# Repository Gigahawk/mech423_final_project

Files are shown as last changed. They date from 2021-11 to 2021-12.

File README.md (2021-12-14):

# LitePog

LitePog is a clone of the [Light Pong](https://www.playlightpong.com/) game.

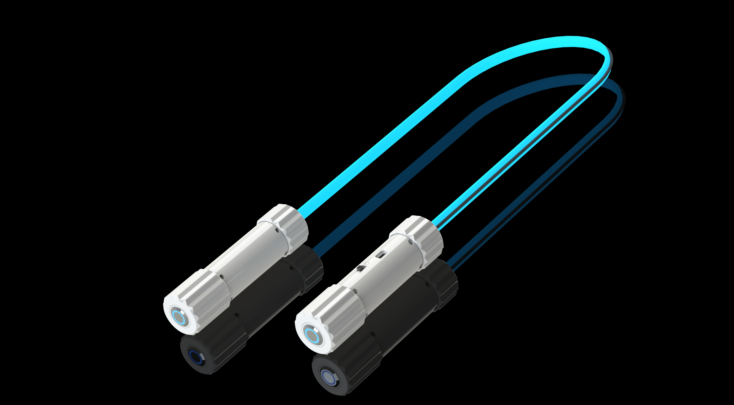
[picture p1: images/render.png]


## Folder Structure
- `firmware`: Code Composer Studio workspace containing firmware for the MSP430FR5739
- `mech`: SolidWorks mechanical CAD files
- `pcb`: KiCad electrical CAD files
- `wiring`: WireViz wire harness diagrams and diagrams.net system wiring diagram
- `proposal`: Initial project proposal for MECH 423 written in LaTeX
- `report`: Final project report for MECH 423 written in LaTeX
- `images`: Images for this readme

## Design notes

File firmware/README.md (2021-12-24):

# LitePog Firmware

## Config Constants

Hardware specific configuration should go inside `config.h`.

## Building

Ensure you are building for the correct target platform:
Right click project > `Build Configurations` > `Set Active` > your platform.

## Design Spec

### Terminology

- `Button 1`: The button connected to the logic PCB
- `Button 2`: The button connected to the power PCB
- `Handle 1`: The handle containing the logic PCB
- `Handle 2`: The handle containing the power PCB
- `Ball`: Single pixel of light that players must keep from reaching their handle
- `Return Zone`: Area that the ball must be in for a player to interact with the ball (in certain game modes)

### Revision 2

The following notes are for the specification designed below, implemented as of [firmware_rev2](https://github.com/Gigahawk/mech423_final_project/tree/firmware_rev2/firmware) (commit hash 8e8a770)

#### Playtest Notes

- Game Select Mode
    - Works well, reasonably intuitive given the lack of buttons
- Play Mode
    - Return zone should not be pure blue, probably best to make the hue slightly different to improve contrast
    - **Pong**
        - Works much better than Rev 1
        - Better anti-spam may be required
            - Cooldown between button presses to penalize double presses
    - **Ping Pong**
        - Works as expected
        - Anti-spam works fine
    - **Tug o' War**
        - May be better to experiment with how exactly the button interacts with the ball
            - Buttons should probably change the velocity of the ball instead of position directly
                - In this case there should be some natural decay of the ball speed towards 0 so that it doesn't move if nothing is pressed.
            - Should investigate benefits of punishing/helping losing player (when ball is near their handle)

#### Specification
The following will outline the expected behavior of LitePog.

##### Game Select Mode

1. User powers up LitePog while holding down Button 2
2. LitePog displays the demo animation of the currently selected game, as well as a rainbow pattern near Handle 2
3. User(s) can choose the next or previous games by pressing Button 1 or Button 2
4. The selection is saved to FRAM when the device is turned off

##### Play Mode

1. User powers up LitePog with no buttons held down.
2. LitePog displays the demo animation of the currently selected game
    - LitePog leaves idle animation when both buttons are held
3. Game count down starts
    - One or two red pixels in the middle light up, and grows outwards at regular interval
    - Once the countdown ends, all red pixels turn green
    - If either player releases their button at this point, return to the demo animation
4. Game is active
    - See below for game types
5. Display game end animation
    - Winner side blinks green, loser side blinks red
    - Return to idle animation after a few seconds

##### Pong

1. The first player to release their button spawns the ball in the middle, the ball starts travelling away from this player
2. Once the ball reaches the return zone of a player, (indicated by their button lighting up), they must press their button to return the ball
    - The return zone should be a few pixels in width
    - If the player fails to return the ball, the game ends

##### Ping Pong

1. The first player to release their button spawns the ball in the middle, the ball starts travelling away from this player
2. Once the ball reaches the return zone of a player, (indicated by their button lighting up), they must press their button to return the ball
    - The return zone should take up half of the light strip
    - If the player fails to return the ball, the game ends
    - If a player presses their button while the ball is not in their return zone and travelling towards them, the game ends

##### Tug o' War

1. The first player to release their button spawns the ball in the middle, the ball starts travelling away from this player
2. Each time the players press a button, the ball moves one pixel away from them
3. If the ball reaches a player's handle, the game ends

### Revision 1

The following notes are for the specification designed below, implemented as of [firmware_rev1](https://github.com/Gigahawk/mech423_final_project/tree/firmware_rev1/firmware) (commit hash 97b537f)

#### Playtest Notes

- Timing is both too slow and too fast
    - Movement of ball between handles takes too long, but the window to return a ball is too small, no good middle ground exists
        - Solution(s):
            - Player should be able to return the ball when the ball reaches a few LEDs prior to the last one (button should light up a few LEDs earlier)
                - This gives greater flexibility to find timing values that are both fun and challenging to play with.
            - Implement the game as shown in the promo video (see below)
- No speaker
    - No solution, the commercial product has more room due to injection molded parts, and more freedom with PCB sizing.
- Only one game mode
    - The commercial product appears to have extra buttons for game selection
        - Solution: Game select mode is handled by holding down the power handle button while flicking the switch, then the two buttons can be used to scroll through the game types.
        The selected game type is stored in FRAM, then the user power cycles the unit, and a demo animation unique to the game starts playing
    - Game Types from [promo video](https://www.youtube.com/watch?v=iOcHVvs48tQ):
        - Ping Pong:
            - Similar to current game, but player can press button to return the ball any time as soon as it passes the middle point.
            - Player loses if they push the button while it's on the other player's side
                - There is also supposedly anti-spam code, although this seems redundant
                - It may be fun to have a mechanic to incentivize waiting for longer before returning the ball (risks losing the game if player waits too long and the ball reaches their end) some potential examples:
                    - Ball returns faster depending on how close it is to the player
                    - Opponents reigion to return the ball gets smaller
        - Rev & Release:
            - This appears to be a single player game where you hold the button to shoot the ball down the tube, then release at a certain point.
                - Single player games don't look very fun, and will not be implemented
        - Tug o' War:
            - Each player button mashes to move the ball closer to the opponent side (think [egg blowing game](https://www.youtube.com/watch?v=yyNyL65NAKE) but less gross)
                - The commercial game uses buttons that are much nicer to spam with, this may cause pain on our buttons
        - Cyclone:
            - I have no idea how this is supposed to work, but this also appears to be a single player game.
                - Single player games don't look very fun, and will not be implemented

#### Specification
The following will outline the expected behavior of LitePog.

1. User powers up LitePog
2. LitePog displays its idle animation
    - LED strip displays either a rainbow cycling effect (power source permitting), or a simple dot moving back and forth.
    - Buttons light up when pressed
    - LitePog leaves idle animation when both buttons are held
3. Game count down starts
    - One or two red pixels in the middle light up, and grows outwards at regular interval
    - Once the countdown ends, all red pixels turn green
    - If either player releases their button at this point, return to the idle animation
4. Game is active
    - The first player to release their button spawns the ball in the middle, the ball starts travelling away from this player
5. Ball reaches player
    - The player must press the button when the ball reaches their side (indicated by the button lighting up) to continue the rally
    - If the player fails to return the ball, the game ends
6. Display game end animation
    - Winner side blinks green, loser side blinks red
    - Return to idle animation after a few seconds

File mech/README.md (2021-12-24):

# LitePog Mechanical CAD

Mechanical CAD files for LitePog

## Exporting for 3D Printing

To export parts for 3D printing, open them in SolidWorks and save as `.3MF`.

Some parts contain multiple bodies, when importing the `.3MF` files into a slicer, ensure each body is treated as a separate part.

All parts should be printable without supports.
> Note: bridges and overhangs may not print well, but they will not be visible from the outside nor cause interference issues.

The list of required parts is:
- `strip_holder.SLDPRT` x2
- `strip_collar.SLDPRT` x2
- `button_plate.SLDPRT` x2
- `button_spacer.SLDPRT` x2
- `button_collar.SLDPRT` x2
- `handle_core.SLDPRT`
    - `logic_handle` configuration x1
    - `power_handle` configuration x1

## Rev 2 Notes

The following notes refer to [mech_rev2](https://github.com/Gigahawk/mech423_final_project/tree/mech_rev2) (commit hash a1e2143).

Hardware has not been validated as of 2021-12-16, however it is likely that this revision will be functional out of the box.

Notable changes:
- PCBs are now centered within handle
    - Power switch sticks out less
    - USB-C countersink is deeper
- External screws have been removed
    - Screw holes were left unused during rev 1 testing
- Optimizations for 3D printing
    - Fewer overhangs
    - Wall thickness is more consistent
- Alignment features for shim pieces
    - Removal of screws means there the old alignment procedure no longer works, so this is now integrated into the design

## Rev 1 Notes

The following notes refer to [mech_rev1](https://github.com/Gigahawk/mech423_final_project/tree/mech_rev1/mech) (commit hash a887341).

### Playtest Notes
- Button placement is uncomfortable
    - Solutions:
        - Make handle's more narrow
            - Handle size is largely constrained by PCB design, which needs to be cost-effective (within 10x10cm), and easy to assemble.
        - Place button on side
            - Will require major redesign
        - Use a bigger/protruding arcade style button
            - Ideal for a next revision, but arcade buttons can be expensive

### Assembly Notes
- Thread features work smoothly
- LED strip clamp could be better designed
    - Currently the clamping force is transmitted through hot glue covering the LED strip solder joints
- Wall thickness is insufficient in many areas
    - Some areas are unfixable, like screw holes
- Screw holes are unnecessary
    - Sandwich mount works fine with just the collars holding the pieces together

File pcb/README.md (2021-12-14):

# LitePog PCB

PCB files for LitePog

## Rev 2 Bring-Up Notes

The following notes refer to [pcb_rev2](https://github.com/Gigahawk/mech423_final_project/tree/pcb_rev2/pcb) (commit hash 8e8a57b).

Hardware has not been validated as of 2021-12-13, however it is likely that this revision will be functional out of the box.

## Rev 1 Bring-Up Notes

The following notes refer to [pcb_rev1](https://github.com/Gigahawk/mech423_final_project/tree/pcb_rev1/pcb) (commit hash f791dd6).

All hardware (with modifications) has been validated as of 2021-11-27.

### Logic Handle (assembled 2021-11-17)
Logic handle was assembled and tested over multiple days:
- 2021-11-17: Initial bring up and testing of all components
- 2021-11-24:
    - Validate Neopixel function with 3.3V logic level
    - Fix transistor connection for button LED

Notes:
- MCU appears to work fine
    - Can be programmed as expected
    - Resonator `Y1` not populated for now, likely not necessary
        - Firmware can rely entirely on DCO
- Power supply works fine
    - Produces 3.3V as expected
- Level shifter doesn't work
    - Level shifter U2 is designed to be connected between open-drain (or push-pull) pins, not to be connected directly to buttons or LEDs.
    - Solutions:
        - Remove/bypass the shifter (**Current solution as of 2021-11-17**)
            - The only strictly 5V level interface is the Neopixel strip, although it is fairly likely to work at 3.3V
            - All other IO is OK to run at 3.3V
            - *EDIT 2021-11-24: Neopixel strip works fine with 3.3V logic signals, level shifter has been removed, and all bypass jumpers set*
        - Use shifters with explicit transfer directions
            - Will need multiple chips, but this will allow all IO to be 5V
        - Only shift the Neopixel data line
            - Minimizes chips, ideal solution for next revision
- LED transistor `Q1` is wired incorrectly
    - Current always flows through body diode regardless of input
    - Solutions:
        - Short `LED-` and `LED1` (*Solution from 2021-11-17*):
            - This inverses the LED on polarity (Set `LED1` to let current flow, high to stop)
            - This sinks 20 mA into the GPIO pin, not ideal.
            - This may cause problems/uneven lighting across the interconnect due to voltage drop.
                - The transistor on the power PCB appears to be correct
        - Flip transistor on PCB (**Current solution as of 2021-11-24**)
            - Pins 1 and 2 need to be swapped (pins on same side of IC), which means pin 3 will be facing the other way. It just so happens that there is a ground pad at approximately the right distance away from the actual transistor footprint that would make this work (or some of the silkscreen can be scratched away)
            - *CORRECTION 2021-11-24: pins 2 and 3 need to be swapped, this was done by rotating IC 180 degrees.*
            *Pin 1 was left floating, which was connected back to R8 with a bodge wire.*
        - Fix transistor configuration in schematic(swap drain and source)
            - ideal solution for next revision
- *EDIT 2021-12-06: LED strip connector `JNPX1` should be moved towards the center by 0.5 to 1mm to avoid interference with the casing.*

### Power Handle
Power handle was assembled over multiple days:
- 2021-11-26: bring up and testing of critical components (boost, charging, protection, in that order)
- 2021-11-27: assemble misc components (connectors, battery holder, button circuitry)
- 2021-12-09: Final testing of safety features

Notes:
- Boost circuit works as designed, capable of producing high current (> 1A continuous for 10 seconds)
- Boost circuit can not be turned off
    - The datasheet for PAM2423 indicates that setting the `EN` pin low only disables the IC's boosting function, it does not turn off the output since there is a direct path from input to output via the inductor and diode.
    - Solutions:
        - Use switch to cut off input current (**Current solution as of 2021-11-26**)
            - Done by cutting the traces going to the input, and running wires to `SW1`.
                - `SW1` is already connected to `BATT+` to drive the `EN` pin, add an extra wire to allow high current flow
            - The EG1224 is only rated for 0.5A, finding higher current switches in this form factor is hard
                - EG2219 is a DPDT switch rated for 0.5A per pole, which can theoretically be combined for 1A total current, but this is still impractical because the input must provide more than 1A current at peak loads
                - Testing at 1A output current (~ 2A input current) seems to be fine (tested for ~10 seconds)
            - This is the simplest solution for this revision, since it does not require `EN` to be rewired, nor does it allow the boost converter to continually drain the battery from quiescent current.
            - There is a risk of arcing if switch is disconnected during high load, although this has not been observed, and should never happen in normal operation
        - Use switch to cut off output current
            - Similar issues to cutting off input current, although current requirements on the output are lower
            - Boost converter will be constantly on, and drawing quiescent current from battery
            - There is a risk of arcing if switch is disconnected during high load, although this has not been observed, and should never happen in normal operation
        - Use MOSFET to switch input current
            - Switch input from high side using a PMOS
            - Ideal solution for next revision
- Charging circuit appears to work as expected
    - LED comes on when plugged in and battery is below max voltage
    - LED turns off when max voltage is reached
    - *EDIT 2021-12-09: Full discharge and charge cycle tested. Charging cutoff occurred at 4.2V as expected*
- Protection circuit appears to work as expected
    - Datasheet for BQ2970 indicates that it must be bootstrapped the first time by connecting a charger to the battery, which was observed
    - *Note: protection features are largely untested*
        - Over discharge current protection is set high enough that it cannot trip
            - This is intentional, we want to allow the battery to provide as much current as necessary for the boost converter
            - A battery capable of providing the necessary current without overheating is being used
        - Short circuit protection is untested
            - This would involve shorting `BATT+` to ground, which is unlikely to happen in regular operation
            - This safety feature is typically intended for standalone battery protection boards that provide user accessible output terminals that could be accidentally shorted
        - Under voltage protection is untested
            - It is time-consuming to wait for the battery to completely drain while monitoring the voltage to ensure that the cutoff protection works.
            - Periodic checking of the battery voltage during firmware development should take place to ensure the battery voltage is within safe levels
            - *EDIT 2021-12-09: Full discharge and charge cycle tested.*
                - Output was shut off at a safe voltage (VBAT ~2.9V when measured, but it may have risen slightly due to hysteresis)
                - It is unclear which chip is actually responsible for cutting off the battery, both the PAM2423 boost converter and the BQ29703DSET protection chip is rated for an under voltage lockout of 2.5V, although it is likely both chips are working as expected.
        - Over voltage protection is untested
            - The charging circuit stops charging the battery prior to the over voltage protection threshold
        - Over charge current protection is untested
            - The charge current of the charging circuit is fixed at 500mA, and should never be high enough to trigger over charge current protection
- Bypass diode `D2` is left unpopulated
    - Theoretically it should be safe to populate, however it is unknown if this will cause adverse behavior with the boost circuit.
    - Populating this diode will prevent the output from being turned off with the switch when `VBUS` is present
- Aluminum capacitors `C10` and `C1` are not structurally sound
    - Should be reinforced with hot glue

### Button Harness (Assembled 2021-11-24)
- Works as expected

### Neopixel Strip (Assembled 2021-11-24)
- Removing provided connectors is rather hard
    - Nearly damaged the pads while removing old joints
    - Simpler solution for next revision is to order more LEDs than required and cut off first one to access unsoldered pads

### Interconnect Harness (Assembled 2021-11-24)
- Works as expected
- Very time-consuming to assemble, set aside more time to do this next revision

### Mock Power Handle (Assembled 2021-11-27)
- Assembled board with bypass diode `D2` connecting the USB connector directly to `VCC`, and button circuitry for use in firmware testing.

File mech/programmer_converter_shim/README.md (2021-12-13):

# MSP-EXP430FR5739 Programmer Breakout Shim

CAD files to support the  [programmer_converter](https://github.com/Gigahawk/mech423_final_project/tree/master/pcb) PCB when connected to the MSP-EXP430FR5739 board.

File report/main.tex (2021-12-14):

\documentclass{notes}
\begin{document}
\vspace*{\fill}
\begin{center}
    {\centering\huge{LitePog}}\\
    \vspace*{2em}
    {\centering\huge{MECH 423 Project Report}}\\
    \vspace*{2em}
    {\large Jasper Chan: 37467164 }\\
    {\large Jacky Chang: 19835164 }
\end{center}
\vspace*{\fill}
\newpage

\begin{abstract}
    The objective of this project is to design and create a simple two player game similar to Light Pong\footnotemark.
    \footnotetext{
        \url{https://www.kickstarter.com/projects/aaqib/light-pong-game}
    }
    The system will consist of two handles/controllers on each end of a flexible tube that houses an LED strip.
    The MSP430 will be used to control the LED's and process the signals from each controller.
    The mechanical housing was designed in SolidWorks and printed in PLA using Fused Deposition Modelling (FDM).
    The PCBs were designed in KiCad and ordered from JLCPCB.

    The game was slightly different from the original Light Pong.
    Our version starts in an idle state and requires both players to hold down their buttons to start a countdown.
    At the end of the countdown the first player to let go launches the "ball" and the light begins to move towards the opposing player.
    Players wait until the button on their handle lights up at which point they would need to press the button before a specified elapses.
    If they fail to do so the game ends, and they lose, if they do press the button in time, the light moves towards the other player at a slightly increased speed.
    This process repeats until one player misses.
\end{abstract}

\section{Objectives}

The project is largely a re-implementation of the Light Pong Kickstarter.
All critical functions of the device were completed, including functional PCBs, a 3D printed housing, and the firmware implementing the game logic.

The only planned feature that was not completed on time was sourcing a translucent/transparent silicone tube to protect the LED strip and wiring.

\section{Rationale}

It's interesting to reverse engineer a product and see what type of difficulties the original developers may have experienced along the way.
The product is still currently only available for preorder, and units are not slated to ship until Q3 2022.
Because it can't be purchased, this is a good opportunity to have a similar device without waiting for preorders to start shipping.

\section{Summary of Functional Requirements}

\begin{table}[H]
    \centering
    \begin{tabularx}{\textwidth}{>{\hsize=.6\hsize\raggedright}X>{\hsize=.1\hsize\raggedright}X>{\hsize=.3\hsize\raggedright\arraybackslash}X}
        Task                                                                    & Effort & Person Responsible \\\toprule
        Power + charging PCB capable of delivering enough current for LED strip & 20\%   & Jasper             \\\midrule
        Microcontroller PCB to drive LED strip and read button inputs           & 20\%   & Jasper             \\\midrule
        Mechanical housing for parts                                            & 20\%   & Jacky              \\\midrule
        Addressable LED Strip                                                   & 5\%    & Jacky              \\ \midrule
        Microcontroller code                                                    & 35\%   & Jasper and Jacky   \\\bottomrule
    \end{tabularx}
    \caption{Functional Requirements and their efforts}
    \label{tab:funcreq}
\end{table}

\section{Functional Requirement 1: Addressable LED strip}

\subsection{Approach and Design}

The most common addressable LED strips on the market are all based on the WS2812B (commonly referred to as Neopixels).
The general rule of thumb is that each LED may consume up to \SI{60}{\milli\ampere} of current, although this rarely happens when displaying patterns on the strip since not all LEDs will be on/at full power.
For our application, Adafruit sells\footnotemark\ a \SI{1}{\meter} long strip with 30 LEDs.
\footnotetext{\url{https://www.adafruit.com/product/1376}}
This provides an acceptable balance between LED density and current consumption.

These LEDs are typically rated for \SI{5}{\volt} power and logic, however they can commonly be driven at lower voltages.
In order to determine the power requirements for the power PCB, experimentation will have to be done.

\subsection{Inputs and Outputs}

\subsubsection{Inputs}

\begin{enumerate}
    \item Power
          \begin{enumerate}
              \item Voltage: nominally \SI{5}{\volt}, actual TBD
              \item Current: Max \SI{60}{\milli\ampere} per LED
          \end{enumerate}
    \item Data: the WS2812B data format is described in the datasheet\footnotemark
          \footnotetext{\url{https://cdn-shop.adafruit.com/datasheets/WS2812.pdf}}
    \item Wiring: Wires between the handles will need to be run along the LED strip
\end{enumerate}

\subsubsection{Outputs}

\begin{enumerate}
    \item Light: the LED strip will emit light
    \item Power: the power wiring inside the LED strip may be used to power the microcontroller PCB
    \item Wiring: Wires between the handles will need to be run along the LED strip
\end{enumerate}

\subsection{Parameters}

\begin{enumerate}
    \item Strip length
          \begin{enumerate}
              \item Adafruit sells strips in \SI{1}{\meter} segments, but they can be cut in between each LED
              \item A \SI{1}{\meter} strip will be used for convenience
          \end{enumerate}
    \item LED count
          \begin{enumerate}
              \item Adafruit sells strips at various LED densities
              \item Higher densities will increase power and memory requirements on the MCU
          \end{enumerate}
\end{enumerate}

\subsection{Development Plan}

For simplicity, a \SI{1}{\meter} strip with 30 LEDs will be used.

A \SI{3.3}{\volt} logic level microcontroller will be used to determine if the strip can be controlled without the use of a level shifter.

A bench power supply will be used to determine if a \SI{5}{\volt} boost circuit will be needed to power the LEDs.

\subsection{Test Plan}
\label{sec:fr1testplan}

\subsubsection{Logic level requirements}
\begin{enumerate}
    \item Power the LED strip with \SI{5}{\volt} from a bench power supply
    \item Connect a \SI{3.3}{\volt} logic level MCU to the data pin of the strip
    \item Attempt to display a test pattern, if this works, a level shifter is not required, if this does not work, redo the test with a level shifter.
\end{enumerate}

\subsubsection{Brightness requirements}
\begin{enumerate}
    \item Power the LED strip with \SI{5}{\volt} from a bench power supply
    \item Connect an MCU to the data pin of the strip
    \item Set all LEDs to full brightness white (RGB 255, 255, 255)
    \item Incrementally turn down the brightness until it is at a reasonable level
\end{enumerate}

\subsubsection{Voltage requirements}
\begin{enumerate}
    \item Power the LED strip with \SI{3.2}{\volt} from a bench power supply
    \item Connect an MCU to the data pin of the strip
    \item Set all LEDs to a reasonable brightness of white
    \item If the LEDs turn on correctly, note the current consumption, if not, repeat the test at a higher voltage until the LED strip reliably turns on.
          \begin{itemize}
              \item This will determine if we need a boost circuit or if the LEDs can be directly powered from a LiPo battery.
          \end{itemize}
\end{enumerate}
\subsubsection{Results}

The LED strip was capable of being controlled with \SI{3.3}{\volt} level logic signals from the MSP430.

It was determined that running the LEDs at about 100/255 brightness was a reasonable number that was clearly visible while keeping the current consumption manageable.

Powering the LED strip at less than \SI{5}{\volt} was not tested since it was determined that a boost converter was necessary to utilize the entirety of the battery capacity.

\subsection{Integration}
\begin{enumerate}
    \item Power the LED strip with the determined acceptable voltage level
    \item Connect MCU (with level shifter if required) to the data pin of the strip
    \item Display a test pattern on the strip
\end{enumerate}

\section{Functional Requirement 2: Power + Charging PCB}
\label{sec:fr2}

\subsection{Approach and Design}

Because there is limited space to store a power source within the handles of the device, a custom PCB will have to be made to hold the battery, and associated charging, protection and boost circuitry as required.

Because the handle will be cylindrical, an 18650 battery will be used because it will be the most convenient form factor while providing high power and energy density.
For safety reasons, a spring-loaded battery holder will be used to avoid soldering or spot welding connections.

\subsection{Inputs and Outputs}

\subsubsection{Inputs}

\begin{enumerate}
    \item Charging power: Battery will be charged with a USB connection
    \item Button: Power PCB will be housed in one of the device handles, and will need to have a connector for the handle button
    \item Button LED signal: Power PCB will need a connection to receive the signal to turn the button's LED on or off
    \item Power Switch: The power PCB will need a power switch to disable the power output
\end{enumerate}

\subsubsection{Outputs}

\begin{enumerate}
    \item LED strip power: Power PCB will need to provide power to the LED strip
    \item Button signal: Power PCB will need to have a connection to deliver the button signal to the MCU
    \item Button LED power: Power PCB will need to light up the button's LED when indicated by the MCU
\end{enumerate}

\subsection{Parameters}

\begin{enumerate}
    \item LED strip voltage: Determined in \autoref{sec:fr1testplan}
    \item Total sustained current: Determined in \autoref{sec:fr1testplan}
    \item Battery choice: Must be capable of providing enough power
          \begin{itemize}
              \item Battery may or may not come with protection circuitry built in.
                    Requirement for protection circuitry on the PCB is only required for unprotected cells.
                    PCB silkscreen will clearly indicate whether protected or unprotected cells should be used.
          \end{itemize}
    \item Charging current: for safety reasons this will be a conservative number (max 1C)
    \item PCB dimensions: PCB must be big enough to hold all the components
\end{enumerate}

\subsection{Development Plan}

\begin{enumerate}
    \item Design schematic and layout of PCB
    \item Send design to PCB house for manufacturing, buy components
    \item Assemble PCB
\end{enumerate}

\subsection{Test Plan}

\subsubsection{Charging}

\begin{enumerate}
    \item Place PCB and USB battery bank inside a fireproof container
    \item Connect USB battery bank to PCB charging input
    \item Wait for charging to complete.
    \item Remove LiPo cell from PCB, ensure that it has the correct voltage for a charged cell (approximately \SI{4.2}{\volt})
\end{enumerate}

\subsubsection{Power Output}

\begin{enumerate}
    \item Place PCB inside a fireproof container
    \item Connect PCB power output to a load
          \begin{itemize}
              \item If the lab contains a programmable load, this is preferred, otherwise the load can just be the LED strip + MCU
          \end{itemize}
    \item Enable PCB power output and load
    \item Ensure power output is stable
    \item Keep test running, ensure power output stops at or before designed battery cutoff voltage is reached.
\end{enumerate}

\subsubsection{Button LED}

\begin{enumerate}
    \item Connect button to PCB
    \item Connect MCU GPIO to PCB
    \item Enable PCB power output
    \item Toggle Button LED GPIO, ensure LED toggles.
\end{enumerate}

\subsubsection{Button Input}

\begin{enumerate}
    \item Connect button to PCB
    \item Connect MCU GPIO to PCB
    \item Enable PCB power output
    \item Press and release button, ensure MCU can read button input.
\end{enumerate}

\subsubsection{Results}

After some modifications\footnotemark, the power PCB functions as expected.
\footnotetext{Modifications are outlined in project files.}

The power PCB was capable of providing \SI{5}{\volt} at \SI{1}{\ampere} continuously for over \SI{10}{\second}, which is more than we ever expect in normal use.
Battery over and under voltage protections worked as expected.
One modification involves running the battery current through the power switch, which exceeds its \SI{500}{\milli\ampere} rating, however no heat or adverse effects were noticed even during prolonged use.

\section{Functional Requirement 3: Microcontroller PCB}

\subsection{Approach and Design}

As required by the class, an MSP430 will be used.
For simplicity, the same MSP430FR5739IDAR\footnotemark as used in Lab 3 will be used, and the design will be derived from the Lab 3 design.
\footnotetext{
    \url{https://www.digikey.ca/en/products/detail/texas-instruments/MSP430FR5739IDAR/2696032}
}

\subsection{Inputs and Outputs}

\subsubsection{Inputs}

\begin{enumerate}
    \item Power: Power will be provided from the PCB board, either via the LED strip, or via a separate wire. Power may have to be stepped down to safely power the MCU
    \item Button x2: MCU PCB will be housed in one of the device handles, and will need to have a connector for the handle button, as well as for the button on the other handle
\end{enumerate}

\subsubsection{Outputs}

\begin{enumerate}
    \item LED strip data: MCU PCB will need to control the LED strip
    \item Button LED power x2: MCU PCB will need to light up the button's LED when indicated by the MCU
\end{enumerate}

\subsection{Parameters}

\begin{enumerate}
    \item Crystal choice: Determine frequency and precision of MCLK source
\end{enumerate}

\subsection{Development Plan}

\begin{enumerate}
    \item Design schematic and layout of PCB
    \item Send design to PCB house for manufacturing, buy components
    \item Assemble PCB
\end{enumerate}

\subsection{Test Plan}

\begin{enumerate}
    \item Power up PCB with bench power supply (use low current limit to minimize risk of shorts)
    \item Check that MCU can be programmed
    \item Program MCU with test firmware
    \item Confirm functionality of all required IO pins with a test program
\end{enumerate}

\subsubsection{Results}

After some modifications\footnotemark, the microcontroller PCB functions as expected.
\footnotetext{Modifications are outlined in project files.}

\section{Functional Requirement 4: Mechanical Housing}

\subsection{Approach and Design}

A custom mechanical housing will have to be designed to house the other components.
To avoid spending too much time or money machining, 3D printing will be primarily used to fabricate mechanical parts.
To make debugging of other components easier, the housing will be designed to be disassembled easily.

\subsection{Inputs and Outputs}

\subsubsection{Inputs}

\begin{enumerate}
    \item Other components: all other components will either be fixed to or contained within the mechanical housing
\end{enumerate}

\subsubsection{Outputs}

\begin{enumerate}
    \item Mechanical stability: parts must be held securely
\end{enumerate}

\subsection{Parameters}

\begin{enumerate}
    \item Handle diameter: diameter must be small enough to be comfortable, but large enough contain the PCBs
    \item Handle length: length must be short enough to be comfortable, but long enough to contain the PCBs
\end{enumerate}

\subsection{Development Plan}

\begin{enumerate}
    \item Once PCBs have been designed, PCB mechanical models will be passed on to the mechanical housing designer
    \item Mechanical housing will be designed around the PCB models
\end{enumerate}

\subsection{Test Plan}

\begin{enumerate}
    \item PCBs (or printed models of the PCBs) will be assembled into the mechanical housings to test fit
\end{enumerate}

\subsubsection{Results}

PCBs were assembled successfully into the housings.

\section{Functional Requirement 5: Microcontroller Code}

\subsection{Approach and Design}

The code for the MCU will need to be written to implement the game behavior.
Once the schematic for the MCU PCB is finalized, code can be written to run on it.

\subsection{Inputs and Outputs}

\subsubsection{Inputs}

\begin{enumerate}
    \item Buttons: The code must read the button inputs at the appropriate time
\end{enumerate}

\subsubsection{Outputs}

\begin{enumerate}
    \item Button LEDs: The code must drive the button LEDs at the appropriate time
    \item LED strip: The code must drive the Neopixel LED strip at the appropriate time with the correct pattern
\end{enumerate}

\subsection{Parameters}

\begin{enumerate}
    \item Game speed: The movement speed of the "ball" will control how hard the game is to play
\end{enumerate}

\subsection{Development Plan}

\begin{enumerate}
    \item Once the schematic is finalized, code can be written for the PCB
\end{enumerate}

\subsection{Test Plan}

\begin{enumerate}
    \item Flash the code on the MCU PCB (or another MSP430 board if the MCU PCB has not been completed)
    \item Hook up the buttons and LED strip and test that the code behaves as expected
\end{enumerate}

\subsubsection{Results}

The code worked as expected, although play testing indicates that changes could be made to improve user experience.

\section{System Evaluation}

See the Results subsections within each Functional Requirements section.

\section{Reflections}

The project for the most part went very smoothly.
We played to our strong points which allowed us to progress quickly; however, it may have proved to be a better learning experience if we worked on our weaker areas.
Some things that we would have done differently is speccing and ordering things earlier.
As a result of this oversight, we were unable to obtain a tube to house the LED strip.
Although the performance didn't suffer, it was still something that we would have liked to have.

The most important things we learned in MECH 423 that we deemed to be the most important are:
\begin{itemize}
    \item Learning how to properly read and interpret documentation
    \item Writing and debugging code
    \item PCB design
\end{itemize}
We picked these three aspects of the course because they are generic topics that are more applicable to the working world as opposed to how to use the MSP430 specifically.
Furthermore, these are things that we believe will be very common for us to use and refer back to as mechatronic engineers; especially within the field of research and development.

Currently, we lack experience implementing mechanical systems.
We have not had very much experience either designing or building a physical system within courses or co-op.
Moving forward, it would be nice to get more practice going through the entire design cycle for a mechanical system so that we may be more proficient in things like designing test jigs or final products.
To acquire this experience, we plan to pursue personal projects with enough difficulty that would challenge our current knowledge and allow us to grow.
We can also achieve this by working in a field that requires rapid iteration and design like a start-up or a research and development position.
\end{document}

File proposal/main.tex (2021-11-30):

\documentclass{notes}
\begin{document}
\vspace*{\fill}
\begin{center}
{\centering\huge{MECH 423 Proposal}}\\
\vspace*{2em}
{\large Jasper Chan: 37467164 }\\
{\large Jacky Chang: 19835164 }
\end{center}
\vspace*{\fill}
\newpage
\section{Objectives}

The objective of this project is to design and create a simple two player game similar to LightPong\footnotemark.
\footnotetext{
    \url{https://www.kickstarter.com/projects/aaqib/light-pong-game}
}
The system will consist of two handles/controllers on each end of a flexible tube that houses an LED strip.
The MSP430 will be used to control the LED's and process the signals from each controller.

\section{Rationale}

It's interesting to reverse engineer a product and see what type of difficulties the original developers may have experienced along the way.
The product is still currently in it's crowdfunding phase, so it's not in full development, and it would be nice to be able to have one to play with.

\section{List of Functional Requirements}

\begin{table}[H]
    \centering
    \begin{tabularx}{\textwidth}
        {
            >{\hsize=.6\hsize\raggedright}X
            >{\hsize=.1\hsize\raggedright}X
            >{\hsize=.3\hsize\raggedright\arraybackslash}X
        }
        Task                                                                    & Effort            & Person Responsible \\\toprule
        Power + charging PCB capable of delivering enough current for LED strip & \SI{20}{\percent} & Jasper             \\\midrule
        Microcontroller PCB to drive LED strip and read button inputs           & \SI{20}{\percent} & Jasper             \\\midrule
        Mechanical housing for parts                                            & \SI{20}{\percent} & Jacky              \\\midrule
        Addressable LED Strip                                                   & \SI{05}{\percent} & Jacky              \\ \midrule
        Microcontroller code                                                    & \SI{35}{\percent} & Jasper and Jacky   \\\bottomrule
    \end{tabularx}
    \caption{Functional Requirements and their efforts}
    \label{tab:funcreq}
\end{table}

\section{Functional Requirement 1: Addressable LED strip}

\subsection{Approach and Design}

The most common addressable LED strips on the market are all based on the WS2812B (commonly referred to as Neopixels).
The general rule of thumb is that each LED may consume up to \SI{60}{\milli\ampere} of current, although this rarely happens when displaying patterns on the strip since not all LEDs will be on/at full power.
For our application, Adafruit sells\footnotemark\ a \SI{1}{\meter} long strip with 30 LEDs.
\footnotetext{\url{https://www.adafruit.com/product/1376}}
This provides an acceptable balance between LED density and current consumption.

These LEDs are typically rated for \SI{5}{\volt} power and logic, however they can commonly be driven at lower voltages.
In order to determine the power requirements for the power PCB, experimentation will have to be done.

\subsection{Inputs and Outputs}

\subsubsection{Inputs}

\begin{enumerate}
    \item Power
    \begin{enumerate}
        \item Voltage: nominally \SI{5}{\volt}, actual TBD
        \item Current: Max \SI{60}{\milli\ampere} per LED
    \end{enumerate}
    \item Data: the WS2812B data format is described in the datasheet\footnotemark
    \footnotetext{\url{https://cdn-shop.adafruit.com/datasheets/WS2812.pdf}}
    \item Wiring: Wires between the handles will need to be run along the LED strip
\end{enumerate}

\subsubsection{Outputs}

\begin{enumerate}
    \item Light: the LED strip will emit light
    \item Power: the power wiring inside the LED strip may be used to power the microcontroller PCB
    \item Wiring: Wires between the handles will need to be run along the LED strip
\end{enumerate}

\subsection{Parameters}

\begin{enumerate}
    \item Strip length
    \begin{enumerate}
        \item Adafruit sells strips in \SI{1}{\meter} segments, but they can be cut in between each LED
        \item A \SI{1}{\meter} strip will be used for convenience
    \end{enumerate}
    \item LED count
    \begin{enumerate}
        \item Adafruit sells strips at various LED densities
        \item Higher densities will increase power and memory requirements on the MCU
    \end{enumerate}
\end{enumerate}

\subsection{Development Plan}

For simplicity, a \SI{1}{\meter} strip with 30 LEDs will be used.

A \SI{3.3}{\volt} logic level microcontroller will be used to determine if the strip can be controlled without the use of a level shifter.

A bench power supply will be used to determine if a \SI{5}{\volt} boost circuit will be needed to power the LEDs.

\subsection{Test Plan}
\label{sec:fr1testplan}

\subsubsection{Logic level requirements}
\begin{enumerate}
    \item Power the LED strip with \SI{5}{\volt} from a bench power supply
    \item Connect a \SI{3.3}{\volt} logic level MCU to the data pin of the strip
    \item Attempt to display a test pattern, if this works, a level shifter is not required, if this does not work, redo the test with a level shifter.
\end{enumerate}

\subsubsection{Brightness requirements}
\begin{enumerate}
    \item Power the LED strip with \SI{5}{\volt} from a bench power supply
    \item Connect an MCU to the data pin of the strip
    \item Set all LEDs to full brightness white (RGB 255, 255, 255)
    \item Incrementally turn down the brightness until it is at a reasonable level
\end{enumerate}

\subsubsection{Voltage requirements}
\begin{enumerate}
    \item Power the LED strip with \SI{3.2}{\volt} from a bench power supply
    \item Connect an MCU to the data pin of the strip
    \item Set all LEDs to a reasonable brightness of white
    \item If the LEDs turn on correctly, note the current consumption, if not, repeat the test at a higher voltage until the LED strip reliably turns on.
    \begin{itemize}
        \item This will determine if we need a boost circuit or if the LEDs can be directly powered from a LiPo battery.
    \end{itemize}
\end{enumerate}

\subsection{Integration}
\begin{enumerate}
    \item Power the LED strip with the determined acceptable voltage level
    \item Connect MCU (with level shifter if required) to the data pin of the strip
    \item Display a test pattern on the strip
\end{enumerate}

\section{Functional Requirement 2: Power + Charging PCB}
\label{sec:fr2}

\subsection{Approach and Design}

Because there is limited space to store a power source within the handles of the device, a custom PCB will have to be made to hold the battery, and associated charging, protection and boost circuitry as required.

Because the handle will be cylindrical, an 18650 battery will be used because it will be the most convenient form factor while providing high power and energy density.
For safety reasons, a spring-loaded battery holder will be used to avoid soldering or spot welding connections.

\subsection{Inputs and Outputs}

\subsubsection{Inputs}

\begin{enumerate}
    \item Charging power: Battery will be charged with a USB connection
    \item Button: Power PCB will be housed in one of the device handles, and will need to have a connector for the handle button
    \item Button LED signal: Power PCB will need a connection to receive the signal to turn the button's LED on or off.
    \item Power Switch: The power PCB will need a power switch to disable the power output.
\end{enumerate}

\subsubsection{Outputs}

\begin{enumerate}
    \item LED strip power: Power PCB will need to provide power to the LED strip
    \item Button signal: Power PCB will need to have a connection to deliver the button signal to the MCU
    \item Button LED power: Power PCB will need to light up the button's LED when indicated by the MCU
\end{enumerate}

\subsection{Parameters}

\begin{enumerate}
    \item LED strip voltage: Determined in \autoref{sec:fr1testplan}
    \item Total sustained current: Determined in \autoref{sec:fr1testplan}
    \item Battery choice: Must be capable of providing enough power
    \begin{itemize}
        \item Battery may or may not come with protection circuitry built in.
        Requirement for protection circuitry on the PCB is only required for unprotected cells.
        PCB silkscreen will clearly indicate whether protected or unprotected cells should be used.
    \end{itemize}
    \item Charging current: for safety reasons this will be a conservative number (max 1C)
    \item PCB dimensions: PCB must be big enough to hold all the components
\end{enumerate}

\subsection{Development Plan}

\begin{enumerate}
    \item Design schematic and layout of PCB
    \item Send design to PCB house for manufacturing, buy components
    \item Assemble PCB
\end{enumerate}

\subsection{Test Plan}

\subsubsection{Charging}

\begin{enumerate}
    \item Place PCB and USB battery bank inside a fireproof container
    \item Connect USB battery bank to PCB charging input
    \item Wait for charging to complete.
    \item Remove LiPo cell from PCB, ensure that it has the correct voltage for a charged cell (approximately \SI{4.2}{\volt})
\end{enumerate}

\subsubsection{Power Output}

\begin{enumerate}
    \item Place PCB inside a fireproof container
    \item Connect PCB power output to a load
        \begin{itemize}
            \item If the lab contains a programmable load, this is preferred, otherwise the load can just be the LED strip + MCU
        \end{itemize}
    \item Enable PCB power output and load
    \item Ensure power output is stable
    \item Keep test running, ensure power output stops at or before designed battery cutoff voltage is reached.
\end{enumerate}

\subsubsection{Button LED}

\begin{enumerate}
    \item Connect button to PCB
    \item Connect MCU GPIO to PCB
    \item Enable PCB power output
    \item Toggle Button LED GPIO, ensure LED toggles.
\end{enumerate}

\subsubsection{Button Input}

\begin{enumerate}
    \item Connect button to PCB
    \item Connect MCU GPIO to PCB
    \item Enable PCB power output
    \item Press and release button, ensure MCU can read button input.
\end{enumerate}

\section{Functional Requirement 3: Microcontroller PCB}

\subsection{Approach and Design}

As required by the class, an MSP430 will be used.
For simplicity, the same MSP430FR5739IDAR\footnotemark as used in Lab 3 will be used, and the design will be derived from the Lab 3 design.
\footnotetext{
    \url{https://www.digikey.ca/en/products/detail/texas-instruments/MSP430FR5739IDAR/2696032}
}

\subsection{Inputs and Outputs}

\subsubsection{Inputs}

\begin{enumerate}
    \item Power: Power will be provided from the PCB board, either via the LED strip, or via a separate wire. Power may have to be stepped down to safely power the MCU
    \item Button x2: MCU PCB will be housed in one of the device handles, and will need to have a connector for the handle button, as well as for the button on the other handle
\end{enumerate}

\subsubsection{Outputs}

\begin{enumerate}
    \item LED strip data: MCU PCB will need to control the LED strip
    \item Button LED power x2: MCU PCB will need to light up the button's LED when indicated by the MCU
\end{enumerate}

\subsection{Parameters}

\begin{enumerate}
    \item Crystal choice: Determine frequency and precision of MCLK source
\end{enumerate}

\subsection{Development Plan}

\begin{enumerate}
    \item Design schematic and layout of PCB
    \item Send design to PCB house for manufacturing, buy components
    \item Assemble PCB
\end{enumerate}

\subsection{Test Plan}

\begin{enumerate}
    \item Power up PCB with bench power supply (use low current limit to minimize risk of shorts)
    \item Check that MCU can be programmed
    \item Program MCU with test firmware
    \item Confirm functionality of all required IO pins with a test program
\end{enumerate}

\section{Functional Requirement 4: Mechanical Housing}

\subsection{Approach and Design}

A custom mechanical housing will have to be designed to house the other components.
To avoid spending too much time or money machining, 3D printing will be primarily used to fabricate mechanical parts.
To make debugging of other components easier, the housing will be designed to be disassembled easily.

\subsection{Inputs and Outputs}

\subsubsection{Inputs}

\begin{enumerate}
    \item Other components: all other components will either be fixed to or contained within the mechanical housing
\end{enumerate}

\subsubsection{Outputs}

\begin{enumerate}
    \item Mechanical stability: parts must be held securely
\end{enumerate}

\subsection{Parameters}

\begin{enumerate}
    \item Handle diameter: diameter must be small enough to be comfortable, but large enough contain the PCBs
    \item Handle length: length must be short enough to be comfortable, but long enough to contain the PCBs
\end{enumerate}

\subsection{Development Plan}

\begin{enumerate}
    \item Once PCBs have been designed, PCB mechanical models will be passed on to the mechanical housing designer
    \item Mechanical housing will be designed around the PCB models
\end{enumerate}

\subsection{Test Plan}

\begin{enumerate}
    \item PCBs (or printed models of the PCBs) will be assembled into the mechanical housings to test fit
\end{enumerate}

\section{Functional Requirement 5: Microcontroller Code}

\subsection{Approach and Design}

The code for the MCU will need to be written to implement the game behavior.
Once the schematic for the MCU PCB is finalized, code can be written to run on it.

\subsection{Inputs and Outputs}

\subsubsection{Inputs}

\begin{enumerate}
    \item Buttons: The code must read the button inputs at the appropriate time
\end{enumerate}

\subsubsection{Outputs}

\begin{enumerate}
    \item Button LEDs: The code must drive the button LEDs at the appropriate time
    \item LED strip: The code must drive the Neopixel LED strip at the appropriate time with the correct pattern
\end{enumerate}

\subsection{Parameters}

\begin{enumerate}
    \item Game speed: The movement speed of the "ball" will control how hard the game is to play
\end{enumerate}

\subsection{Development Plan}

\begin{enumerate}
    \item Once the schematic is finalized, code can be written for the PCB
\end{enumerate}

\subsection{Test Plan}

\begin{enumerate}
    \item Flash the code on the MCU PCB (or another MSP430 board if the MCU PCB has not been completed)
    \item Hook up the buttons and LED strip and test that the code behaves as expected
\end{enumerate}

\section{Most Critical Module}

The most critical module is the power PCB described in \autoref{sec:fr2}.
The power PCB needs to provide stable power to all the other components.
The power PCB will also be the larger of the two PCBs, and will be the limiting factor in how small the handles can be.

\section{Risks and Countermeasures}

\subsection{Parts Shortage}

We are in the middle of a parts and shipping shortage at time of writing.

To mitigate potential shipping delays, designs will be completed as soon as possible so that parts can be ordered as soon as possible.
To mitigate parts potentially being available, a BOM will be kept up to date as the design progresses, and will be periodically checked with DigiKey to ensure that they are still available.
Where possible, PCBs will be designed to support alternative parts.
The most critical part will be the MSP430FR5739IDAR, which at time of writing is still available.
If it is no longer available at time of purchasing, the chip can be salvaged from the PCB from Lab 3.

\subsection{Limited Power}

The battery or circuitry in the power PCB may not deliver enough power to the rest of the system when assembled.

To mitigate limited power output, the USB charging connector and an auxiliary barrel connector will also be routed to the main power output so that the system can be externally powered.

\section{Learning Objectives}

We hope to further develop both electrical and mechanical CAD skills, as well as programming skills.

\end{document}

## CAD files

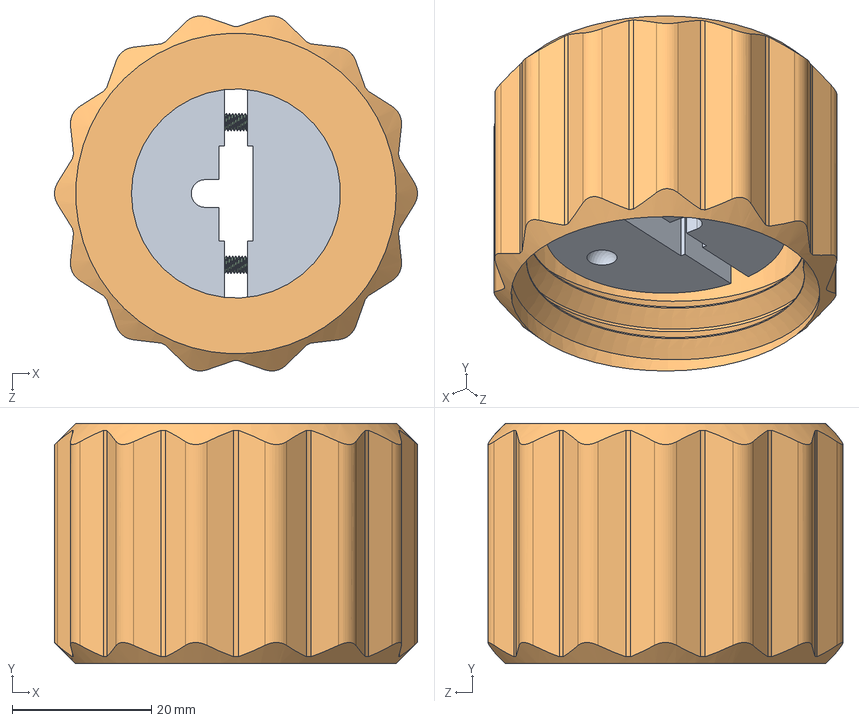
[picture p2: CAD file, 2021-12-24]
mech/strip_holder.SLDASM
52.1 x 34.5 x 50.9 mm
strip_holder
strip_collar
90592A080_Steel Hex Nut x 2
91290A106_Black-Oxide Alloy Steel Socket Head Screw x 2

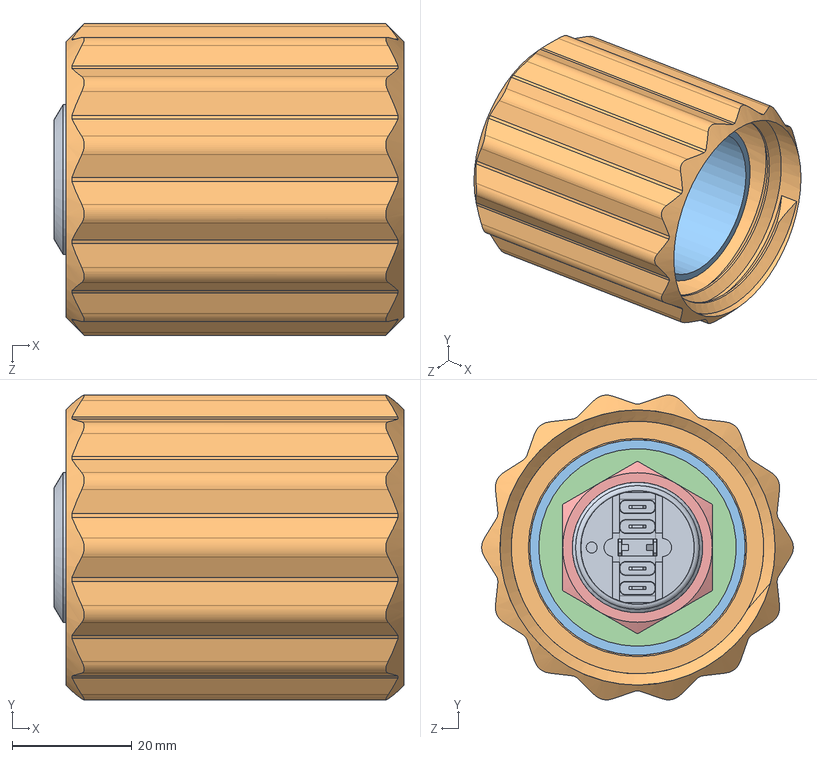
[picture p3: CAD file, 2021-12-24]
mech/button.SLDASM
58.5 x 50.9 x 52.1 mm
PV7F2Y0xx-3xx
button_collar
button_spacer
button_plate
button_nut

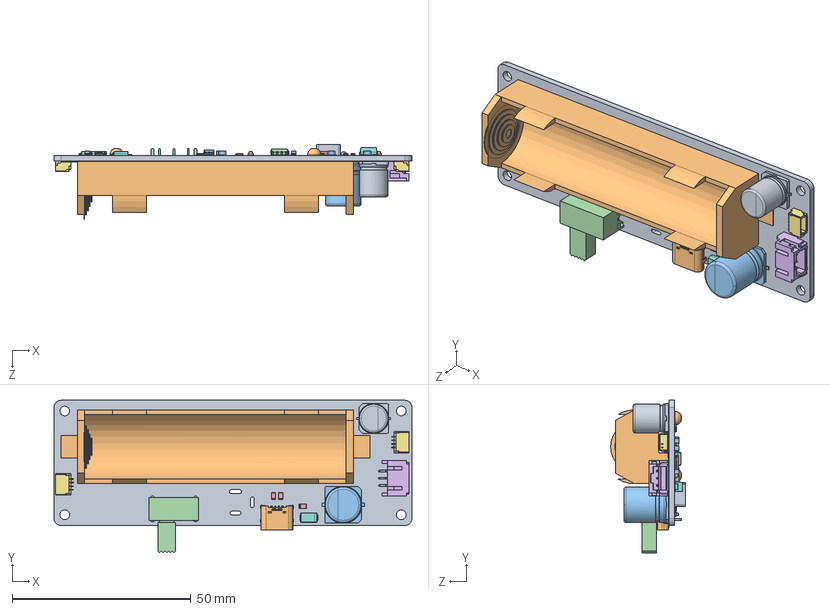
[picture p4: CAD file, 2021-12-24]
mech/power_handle_pcb.SLDASM
100.0 x 42.6 x 20.9 mm
Pcb_ddda.step
UJC-HP-3-SMT-TR.step
C10_CP_Elec_10x126_6184AD54.step
SW1_SW_E-Switch_EG1224_SPDT_Angled_6183ECC2.step
R5_R_0805_2012Metric_6183C6F1.step x 16
JNPX1_S3B-PH-SM4-TB(LF)(SN)_6183D19D.step
JHI1_SM04B-SRSS-TB(LF)(SN)_6183DD0E.step x 2
D4_D_SMA_61848250.step x 2
C1_CP_Elec_8x10_6184FB3E.step
BT1_Keystone_1042_1x18650_6184FC40.step
U1_SOT_23_5_6184FD53.step
Q4_SOIC_8_39x49mm_P127mm_61B79016.step
U2_HSOP_8_1EP_39x49mm_P127mm_EP241x31mm_6183C879.step
U3_WSON6_15x15mm_Pitch05mm_6183C88F.step
Q3_SOT_323_SC_70_6183C69C.step
Q2_LFPAK56_61845DD0.step x 2
L1_ASPI-0630LR-6R8M-T15_6183C61F.step
D6_LED_0603_1608Metric_6183C53E.step x 3
C9_C_0805_2012Metric_6183C4BD.step x 8

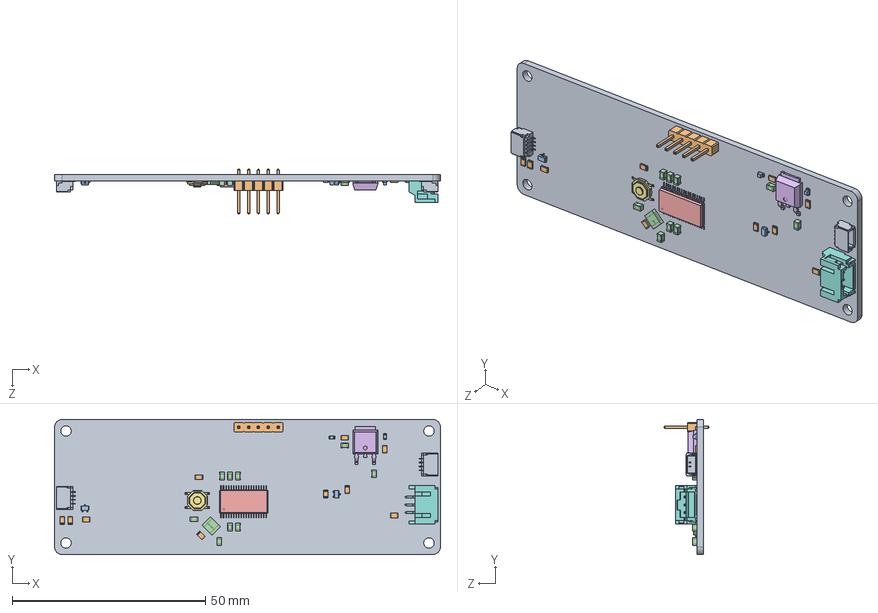
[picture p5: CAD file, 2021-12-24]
mech/logic_handle_pcb.SLDASM
100.0 x 35.0 x 11.5 mm
Pcb_a717.step
R10_R_0805_2012Metric_61B71808.step x 10
Q2_SOT_323_SC_70_61B764EC.step x 2
Y1_AWSZT-CV_618C0FB4.step
U3_TSSOP_38_61x125mm_P065mm_618C0FA4.step
U1_TO_252_2_618C0EA8.step
SW1_SW_SPST_TL3342_618C4494.step
JNPX1_S3B-PH-SM4-TB(LF)(SN)_61B7FB0F.step
JHI1_SM04B-SRSS-TB(LF)(SN)_618C190E.step x 2
J1_PinHeader_1x05_P254mm_Vertical_618C0BB2.step
D2_LED_0603_1608Metric_618C0B79.step x 2
C11_C_0805_2012Metric_618C37EA.step x 9

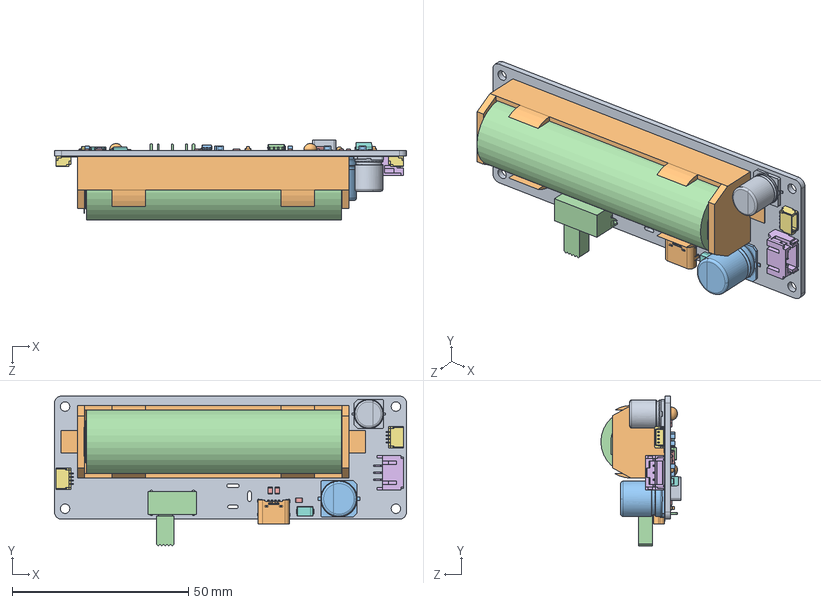
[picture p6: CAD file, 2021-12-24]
mech/power_handle_pcb_with_bat.SLDASM
100.0 x 42.6 x 22.8 mm
Pcb_ddda.step
UJC-HP-3-SMT-TR.step
C10_CP_Elec_10x126_6184AD54.step
SW1_SW_E-Switch_EG1224_SPDT_Angled_6183ECC2.step
R5_R_0805_2012Metric_6183C6F1.step x 16
JNPX1_S3B-PH-SM4-TB(LF)(SN)_6183D19D.step
JHI1_SM04B-SRSS-TB(LF)(SN)_6183DD0E.step x 2
D4_D_SMA_61848250.step x 2
C1_CP_Elec_8x10_6184FB3E.step
BT1_Keystone_1042_1x18650_6184FC40.step
U1_SOT_23_5_6184FD53.step
Q4_SOIC_8_39x49mm_P127mm_61B79016.step
U2_HSOP_8_1EP_39x49mm_P127mm_EP241x31mm_6183C879.step
U3_WSON6_15x15mm_Pitch05mm_6183C88F.step
Q3_SOT_323_SC_70_6183C69C.step
Q2_LFPAK56_61845DD0.step x 2
L1_ASPI-0630LR-6R8M-T15_6183C61F.step
D6_LED_0603_1608Metric_6183C53E.step x 3
C9_C_0805_2012Metric_6183C4BD.step x 8
18650_prot

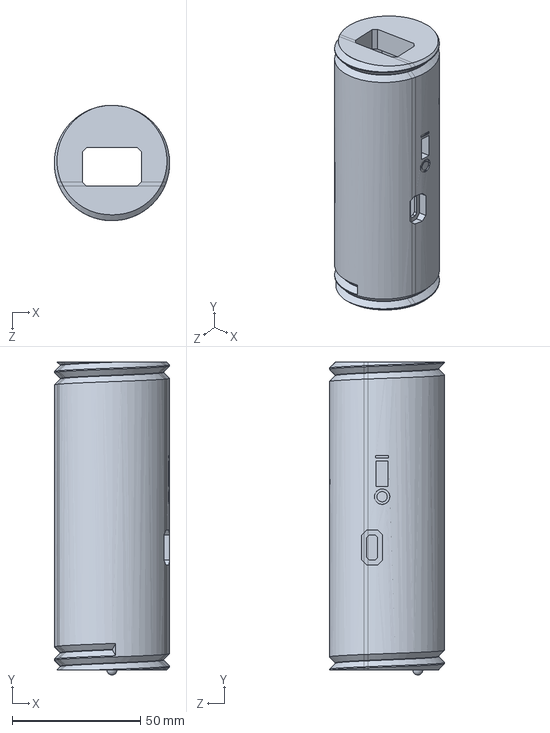
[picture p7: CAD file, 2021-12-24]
mech/handle_core.SLDPRT
45.0 x 122.0 x 45.0 mm

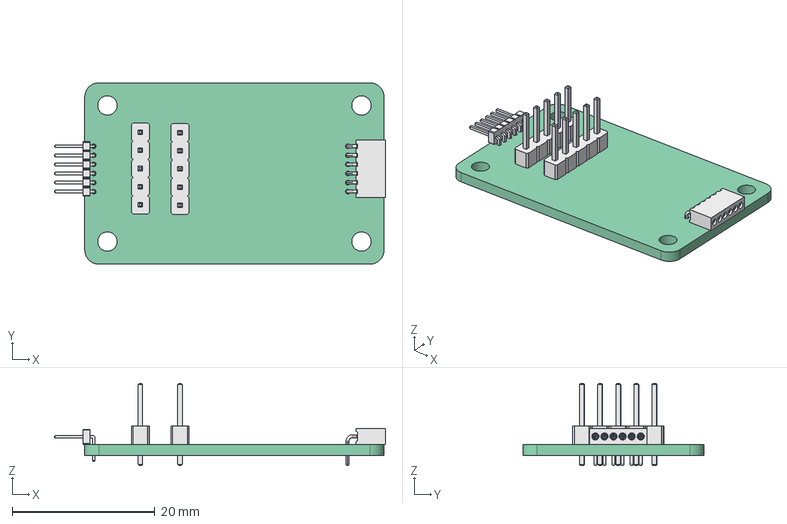
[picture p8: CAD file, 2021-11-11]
pcb/programmer_converter.FCStd
46.3 x 25.4 x 11.5 mm
Pcb_b6f6
J4_PinHeader_1x06_P127mm_Horizontal_6186764A
J3_PinHeader_1x05_P254mm_Vertical_61865A88 x 2
J1_pcb_connector_851-87-006-20-001101_6186592D

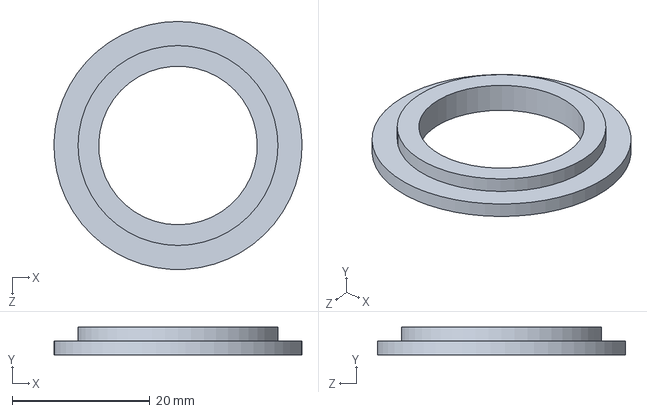
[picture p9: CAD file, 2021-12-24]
mech/button_plate.SLDPRT
36.0 x 4.00 x 36.0 mm

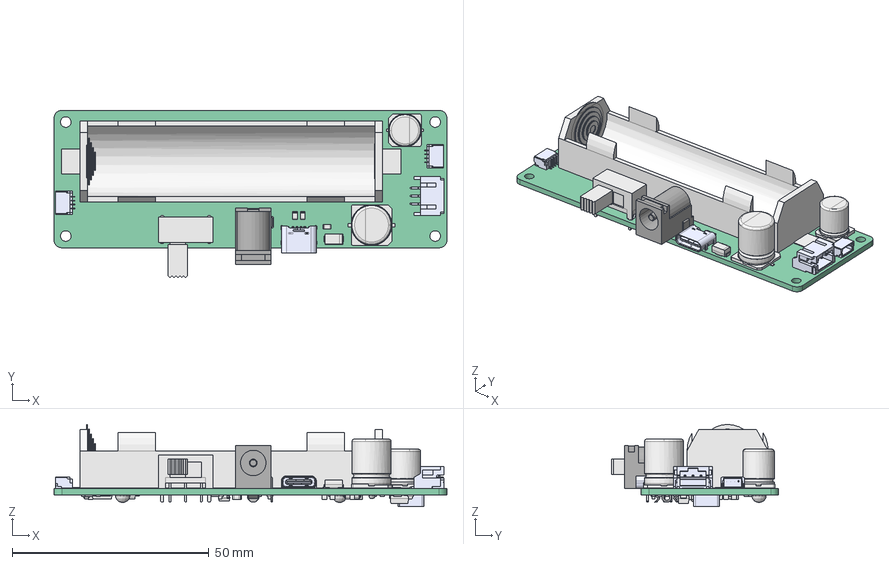
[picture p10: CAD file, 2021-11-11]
pcb/power_handle.FCStd
100.0 x 42.6 x 20.9 mm
Pcb_ddda
C10_CP_Elec_10x126_6184AD54
SW1_SW_E-Switch_EG1224_SPDT_Angled_6183ECC2
R16_R_0805_2012Metric_6183C7AC x 16
JNPX1_S3B-PH-SM4-TB(LF)(SN)_6183D19D
JHI1_SM04B-SRSS-TB(LF)(SN)_6183DD0E x 2
UJC-HP-3-SMT-TR
J1_CUI_DEVICES_PJ-202A_6183EEC8
D4_D_SMA_61848250 x 2
C1_CP_Elec_8x10_6184FB3E
BT1_Keystone_1042_1x18650_6184FC40
U2_HSOP_8_1EP_39x49mm_P127mm_EP241x31mm_6183C879
U3_WSON6_15x15mm_Pitch05mm_6183C88F
U1_SOT_23_5_6184FD53
Q3_SOT_323_SC_70_6183C69C
Q2_LFPAK56_61845DD0 x 2
L1_ASPI-0630LR-6R8M-T15_6183C61F
D6_LED_0603_1608Metric_6183C53E x 3
C9_C_0805_2012Metric_6183C4BD x 8

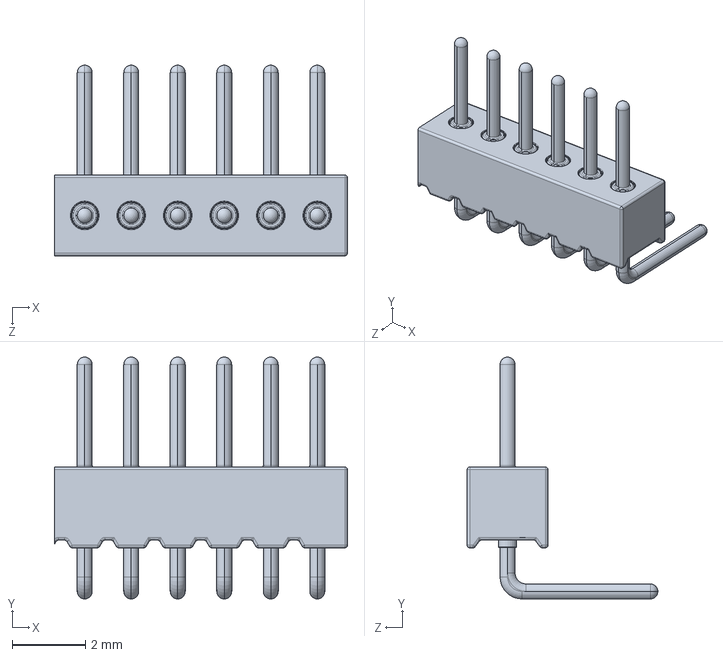
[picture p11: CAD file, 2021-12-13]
mech/programmer_converter_shim/prog_header.SLDPRT
8.00 x 6.61 x 5.21 mm

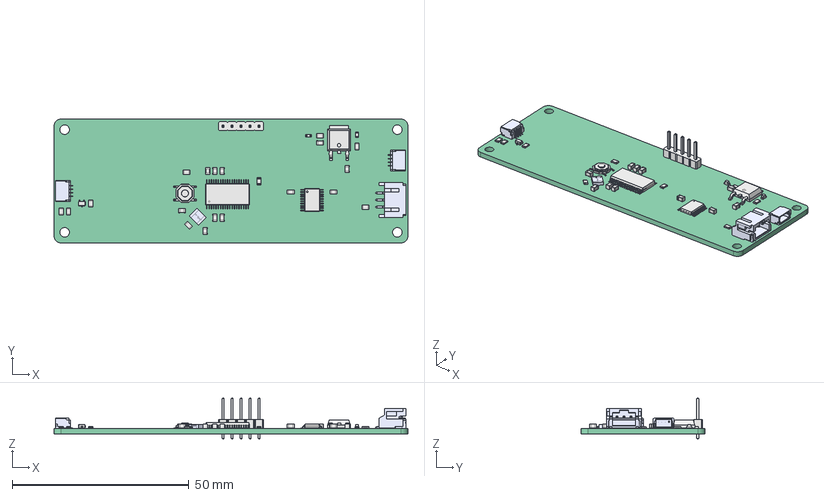
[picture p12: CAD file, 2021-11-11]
pcb/logic_handle.FCStd
100.0 x 35.0 x 11.5 mm
Pcb_a717
Y1_AWSZT-CV_618C0FB4
U3_TSSOP_38_61x125mm_P065mm_618C0FA4
U2_TSSOP_20_44x65mm_P065mm_618C0ECE
U1_TO_252_2_618C0EA8
SW1_SW_SPST_TL3342_618C4494
R9_R_0805_2012Metric_618CEA17 x 9
Q1_SOT_323_SC_70_618C0D0D
JNPX1_S3B-PH-SM4-TB(LF)(SN)_618C1781
JHI1_SM04B-SRSS-TB(LF)(SN)_618C190E x 2
J1_PinHeader_1x05_P254mm_Vertical_618C0BB2
D2_LED_0603_1608Metric_618C0B79 x 2
C11_C_0805_2012Metric_618C37EA x 11

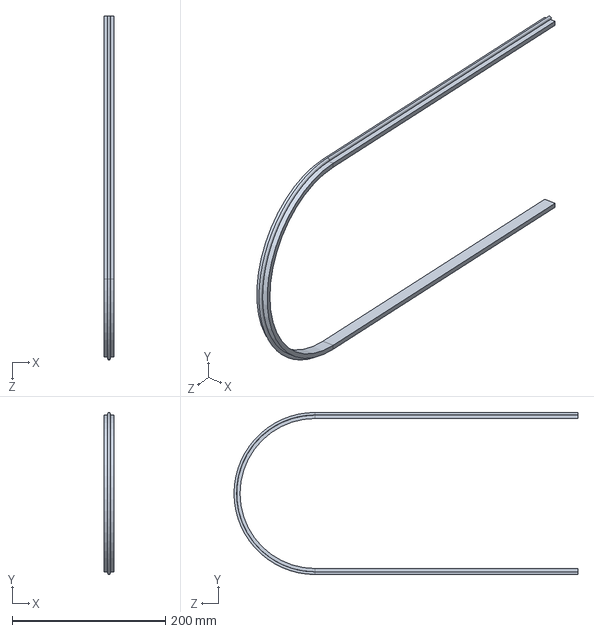
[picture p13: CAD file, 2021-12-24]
mech/led_strip_with_interconnect_cable.SLDPRT
12.5 x 211.4 x 448.6 mm

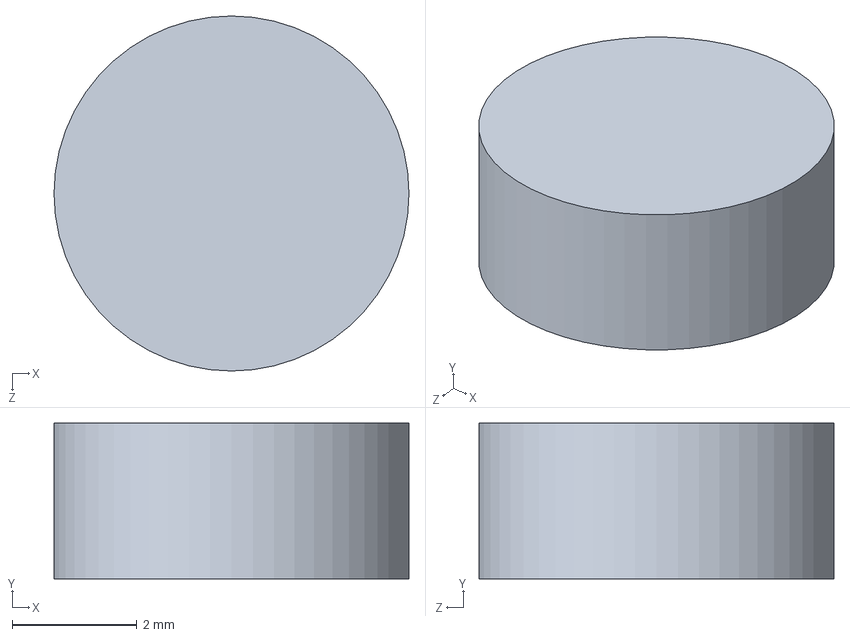
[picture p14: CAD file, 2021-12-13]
mech/programmer_converter_shim/foot.SLDPRT
5.70 x 2.50 x 5.70 mm

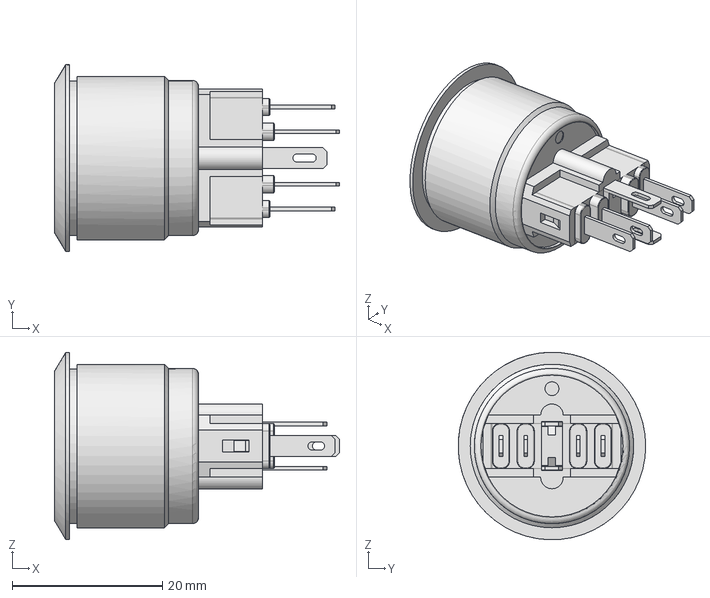
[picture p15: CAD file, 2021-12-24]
mech/PV7F2Y0xx-3xx.stp
38.0 x 25.0 x 25.0 mm

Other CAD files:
mech/programmer_converter_shim/programmer_converter_shim.SLDPRT
mech/programmer_converter_shim/programmer_converter.step
mech/programmer_converter_shim/exp_pcb.SLDPRT
mech/button_spacer.SLDPRT
mech/18650_prot.SLDPRT
mech/90592A080_Steel Hex Nut.SLDPRT
mech/91290A106_Black-Oxide Alloy Steel Socket Head Screw.SLDPRT
mech/PV7F2Y0xx-3xx.SLDPRT
mech/button_collar.SLDPRT
mech/button_nut.SLDPRT
mech/programmer_converter_shim/91292A012_18-8 Stainless Steel Socket Head Screw.SLDPRT
mech/programmer_converter_shim/91828A113_18-8 Stainless Steel Hex Nut.SLDPRT
mech/programmer_converter_shim/98689A111_General Purpose 18-8 Stainless Steel Washer.SLDPRT
mech/programmer_converter_shim/programmer_converter.SLDASM
mech/strip_collar.SLDPRT
mech/strip_holder.SLDPRT

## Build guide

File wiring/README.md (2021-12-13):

# Light Pong Wiring Diagrams

## Wiring Harnesses

Wiring harnesses are defined as [WireViz](https://github.com/formatc1702/WireViz) YAML files, see their page for installation details.

## System Wiring Diagram

The system wiring diagram is a [diagrams.net](https://www.diagrams.net/) file.

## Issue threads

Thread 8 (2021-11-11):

firmware: pin mappings should be defined in a config header

Gigahawk, 2021-11-11:
Different pin mappings are available depending on if the dev board or real PCB is being used, this should be easily configurable.

Gigahawk, 2021-11-16:
fixed by #10

Closed 2021-11-16.

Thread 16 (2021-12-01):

firmware: demoLoop hangs if both buttons held down after game ends

Gigahawk, 2021-12-01:
Countdown appears to start but doesn't display anything and hangs until buttons are released and pressed again

Closed 2021-12-01.

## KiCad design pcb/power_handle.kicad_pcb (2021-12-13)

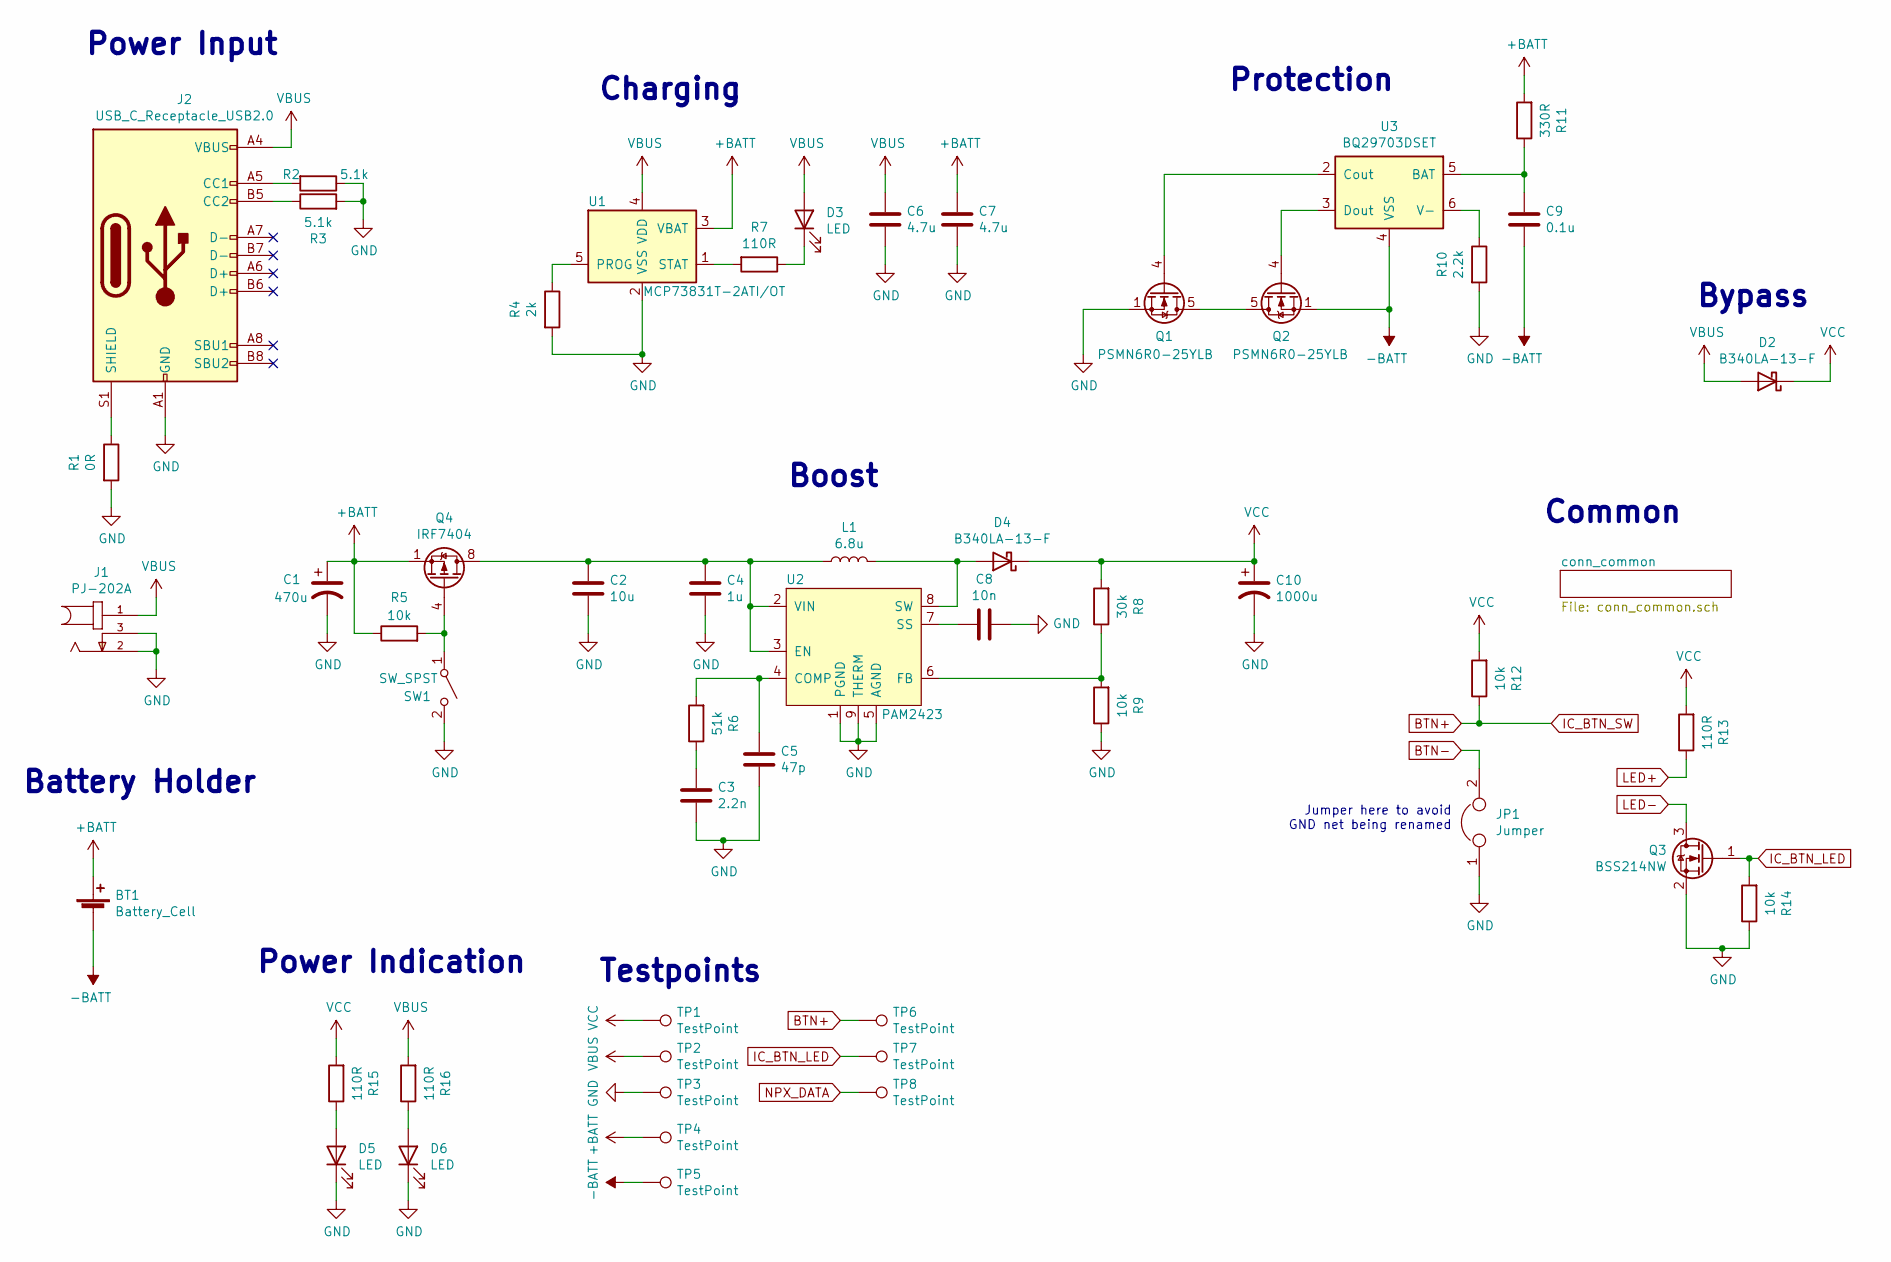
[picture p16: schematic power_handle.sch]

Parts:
BT1: Battery_Cell; BatteryHolder_Keystone_1042_1x18650; Digikey 36-1042-ND
C1: 470u; CP_Elec_8x10; Digikey 732-6451-1-ND
C2: 10u; C_0805_2012Metric; Digikey 1276-6456-1-ND
C3: 2.2n; C_0805_2012Metric; Digikey 1276-2484-1-ND
C4: 1u; C_0805_2012Metric; Digikey 1276-1026-1-ND
C5: 47p; C_0805_2012Metric; Digikey 709-1175-1-ND
C6, C7: 4.7u; C_0805_2012Metric; Digikey 1276-1259-1-ND
C8: 10n; C_0805_2012Metric; Digikey 478-1383-1-ND
C9: 0.1u; C_0805_2012Metric; Digikey 478-10836-1-ND
C10: 1000u; CP_Elec_10x12.6; Digikey 493-13738-1-ND
D2, D4: B340LA-13-F; D_SMA; Digikey 641-1258-1-ND
D3, D5, D6: LED; LED_0603_1608Metric; Digikey 160-1832-1-ND
J1: PJ-202A; CUI_PJ-202A; PART_REV 1.02; Digikey CP-202A-ND
J2: USB_C_Receptacle_USB2.0; UJC-HP-3-SMT-TR; Digikey 2223-UJC-HP-3-SMT-CT-ND
JP1: Jumper; SolderJumper-2_P1.3mm_Bridged2Bar_Pad1.0x1.5mm
L1: 6.8u; ASPI-0630LR-6R8M-T15; Digikey 535-13041-1-ND
Q1, Q2: PSMN6R0-25YLB; LFPAK56; Digikey 1727-6497-1-ND
Q3: BSS214NW; SOT-323_SC-70; Digikey BSS214NWH6327XTSA1CT-ND
Q4: IRF7404; SOIC-8_3.9x4.9mm_P1.27mm; Digikey IRF7404PBFCT-ND
R1: 0R; R_0805_2012Metric; Digikey RMCF0805ZT0R00CT-ND
R2, R3: 5.1k; R_0805_2012Metric; Digikey A126379CT-ND
R4: 2k; R_0805_2012Metric; Digikey RG20N2.0KWCT-ND
R5, R9, R12, R14: 10k; R_0805_2012Metric; Digikey RMCF0805JT10K0CT-ND
R6: 51k; R_0805_2012Metric; Digikey A126373CT-ND
R7, R13, R15, R16: 110R; R_0805_2012Metric; Digikey RMCF0805JT110RCT-ND
R8: 30k; R_0805_2012Metric; Digikey 13-RT0805FRE0730KLCT-ND
R10: 2.2k; R_0805_2012Metric; Digikey A106060CT-ND
R11: 330R; R_0805_2012Metric; Digikey A130131CT-ND
SW1: SW_SPST; SW_E-Switch_EG1224_SPDT_Angled; Digikey EG2585-ND
TP1, TP2, TP3, TP4, TP5, TP6, TP7, TP8: TestPoint; TestPoint_Pad_2.0x2.0mm
U1: MCP73831T-2ATI/OT; SOT-23-5; Digikey MCP73831T-2ATI/OTCT-ND
U2: PAM2423; HSOP-8-1EP_3.9x4.9mm_P1.27mm_EP2.41x3.1mm_HandSolderThermal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; Digikey PAM2423AECADJRDICT-ND
U3: BQ29703DSET; WSON-6_1.5x1.5mm_P0.5mm; Digikey 296-37960-1-ND

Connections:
+BATT: BT1.1 (+), C1.1, C7.1, Q4.1 (S), Q4.2 (S), Q4.3 (S), R5.1, R11.2, TP4.1, U1.3 (VBAT)
-BATT: BT1.2 (-), C9.2, Q2.1 (S), Q2.2 (S), Q2.3 (S), TP5.1, U3.4 (VSS)
BTN+: R12.1, TP6.1; also elsewhere on the board
BTN-: JP1.2; also elsewhere on the board
GND: C1.2, C2.1, C3.1, C4.1, C5.2, C6.2, C7.2, C8.1, C10.2, D5.1 (K), D6.1 (K), J1.2, J1.3, J2.A1 (GND), J2.A12 (GND), J2.B1 (GND), J2.B12 (GND), JP1.1, Q1.1 (S), Q1.2 (S), Q1.3 (S), Q3.2 (S), R1.2, R2.1, R3.2, R4.2, R9.1, R10.2, R14.1, SW1.2 (B), TP3.1, U1.2 (VSS), U2.1 (PGND), U2.5 (AGND), U2.9 (THERM); also elsewhere on the board
IC_BTN_LED: Q3.1 (G), R14.2, TP7.1; also elsewhere on the board
LED+: R13.1; also elsewhere on the board
LED-: Q3.3 (D); also elsewhere on the board
NPX_DATA: TP8.1; also elsewhere on the board
unnamed: C2.2, C4.2, L1.1, Q4.5 (D), Q4.6 (D), Q4.7 (D), Q4.8 (D), U2.2 (VIN), U2.3 (EN)
unnamed: C3.2, R6.1
unnamed: C5.1, R6.2, U2.4 (COMP)
unnamed: C8.2, U2.7 (SS)
unnamed: C9.1, R11.1, U3.5 (BAT)
unnamed: D3.1 (K), R7.1
unnamed: D4.2 (A), L1.2, U2.8 (SW)
unnamed: D5.2 (A), R15.1
unnamed: D6.2 (A), R16.1
unnamed: J2.A5 (CC1), R2.2
unnamed: J2.B5 (CC2), R3.1
unnamed: J2.S1 (SHIELD), R1.1
unnamed: Q1.4 (G), U3.2 (Cout)
unnamed: Q1.5 (D), Q2.5 (D)
unnamed: Q2.4 (G), U3.3 (Dout)
unnamed: Q4.4 (G), R5.2, SW1.1 (A)
unnamed: R4.1, U1.5 (PROG)
unnamed: R7.2, U1.1 (STAT)
unnamed: R8.1, R9.2, U2.6 (FB)
unnamed: R10.1, U3.6 (V-)
VBUS: C6.1, D2.2 (A), D3.2 (A), J1.1, J2.A4 (VBUS), J2.A9 (VBUS), J2.B4 (VBUS), J2.B9 (VBUS), R16.2, TP2.1, U1.4 (VDD)
VCC: C10.1, D2.1 (K), D4.1 (K), R8.2, R12.2, R13.2, R15.2, TP1.1; also elsewhere on the board

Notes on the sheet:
Power Input
Charging
Protection
Boost
Battery Holder
Common
Power Indication
Testpoints
Jumper here to avoid GND net being renamed
Bypass

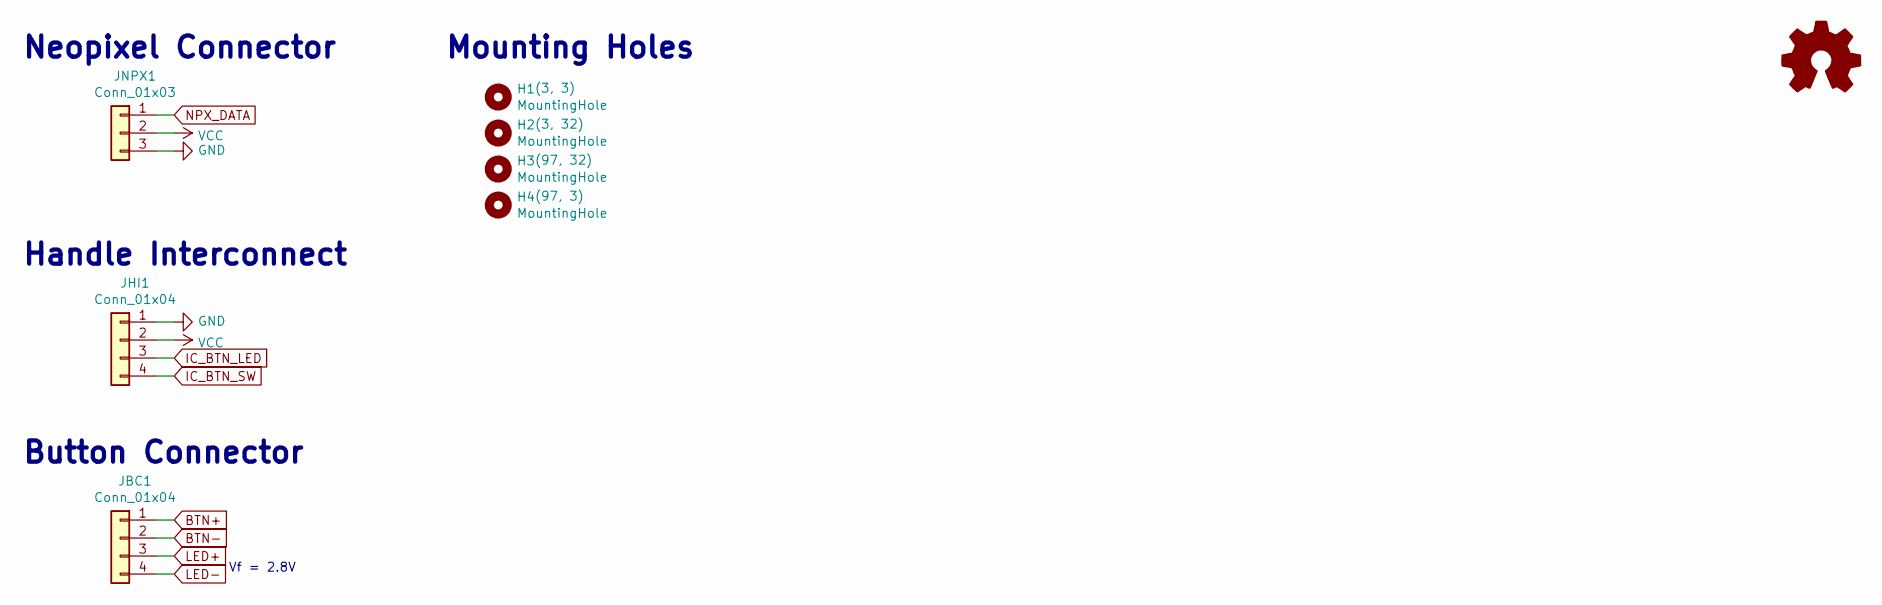
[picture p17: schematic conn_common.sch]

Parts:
H1, H2, H3, H4: MountingHole; MountingHole_2.7mm_M2.5
JBC1: Conn_01x04; JST_SH_SM04B-SRSS-TB_1x04-1MP_P1.00mm_Horizontal; Digikey SM04B-SRSS-TB
JHI1: Conn_01x04; JST_SH_SM04B-SRSS-TB_1x04-1MP_P1.00mm_Horizontal; Digikey SM04B-SRSS-TB
JNPX1: Conn_01x03; JST_PH_S3B-PH-SM4-TB_1x03-1MP_P2.00mm_Horizontal; Digikey 455-1750-1-ND
LOGO1: Logo_Open_Hardware_Small; OSHW-Logo_5.7x6mm_SilkScreen

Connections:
BTN+: JBC1.1, JHI1.4; also elsewhere on the board
BTN-: JBC1.2; also elsewhere on the board
GND: JHI1.1, JNPX1.3; also elsewhere on the board
IC_BTN_LED: JHI1.3; also elsewhere on the board
LED+: JBC1.3; also elsewhere on the board
LED-: JBC1.4; also elsewhere on the board
NPX_DATA: JNPX1.1; also elsewhere on the board
VCC: JHI1.2, JNPX1.2; also elsewhere on the board

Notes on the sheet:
Neopixel Connector
Handle Interconnect
Button Connector
Vf = 2.8V
Mounting Holes

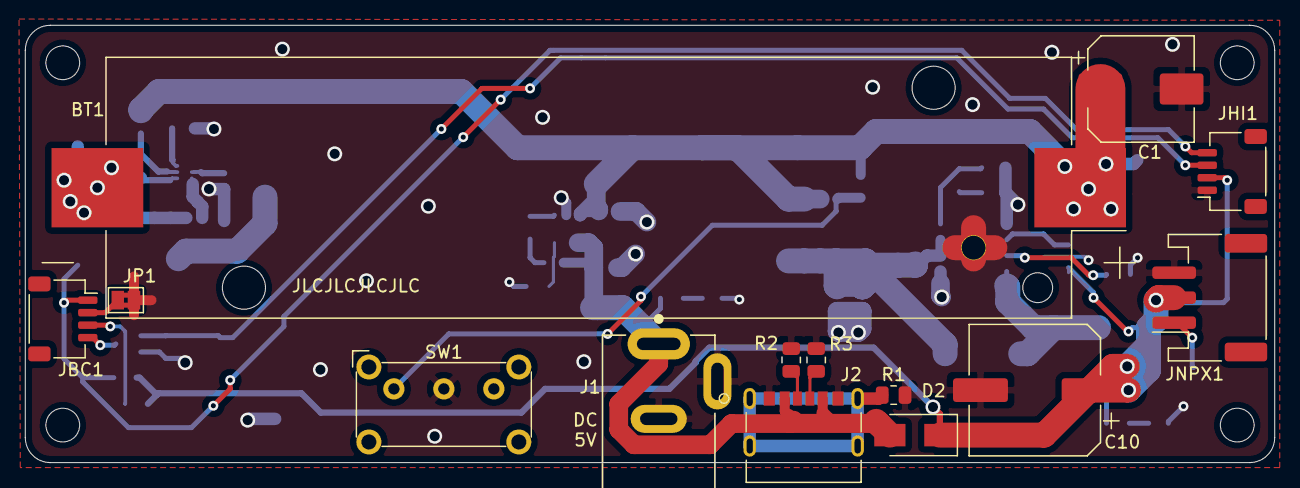
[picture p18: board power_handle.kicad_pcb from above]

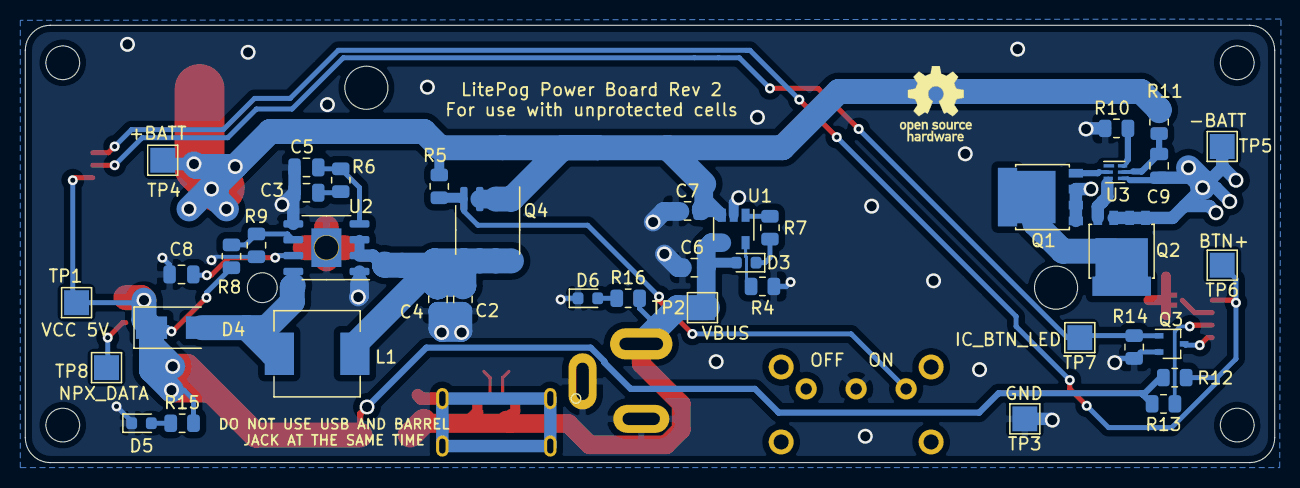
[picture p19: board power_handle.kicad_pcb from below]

Board: 2 copper layers, 100.0 x 35.0 mm, 60 parts (42 on the bottom side), 31 nets.

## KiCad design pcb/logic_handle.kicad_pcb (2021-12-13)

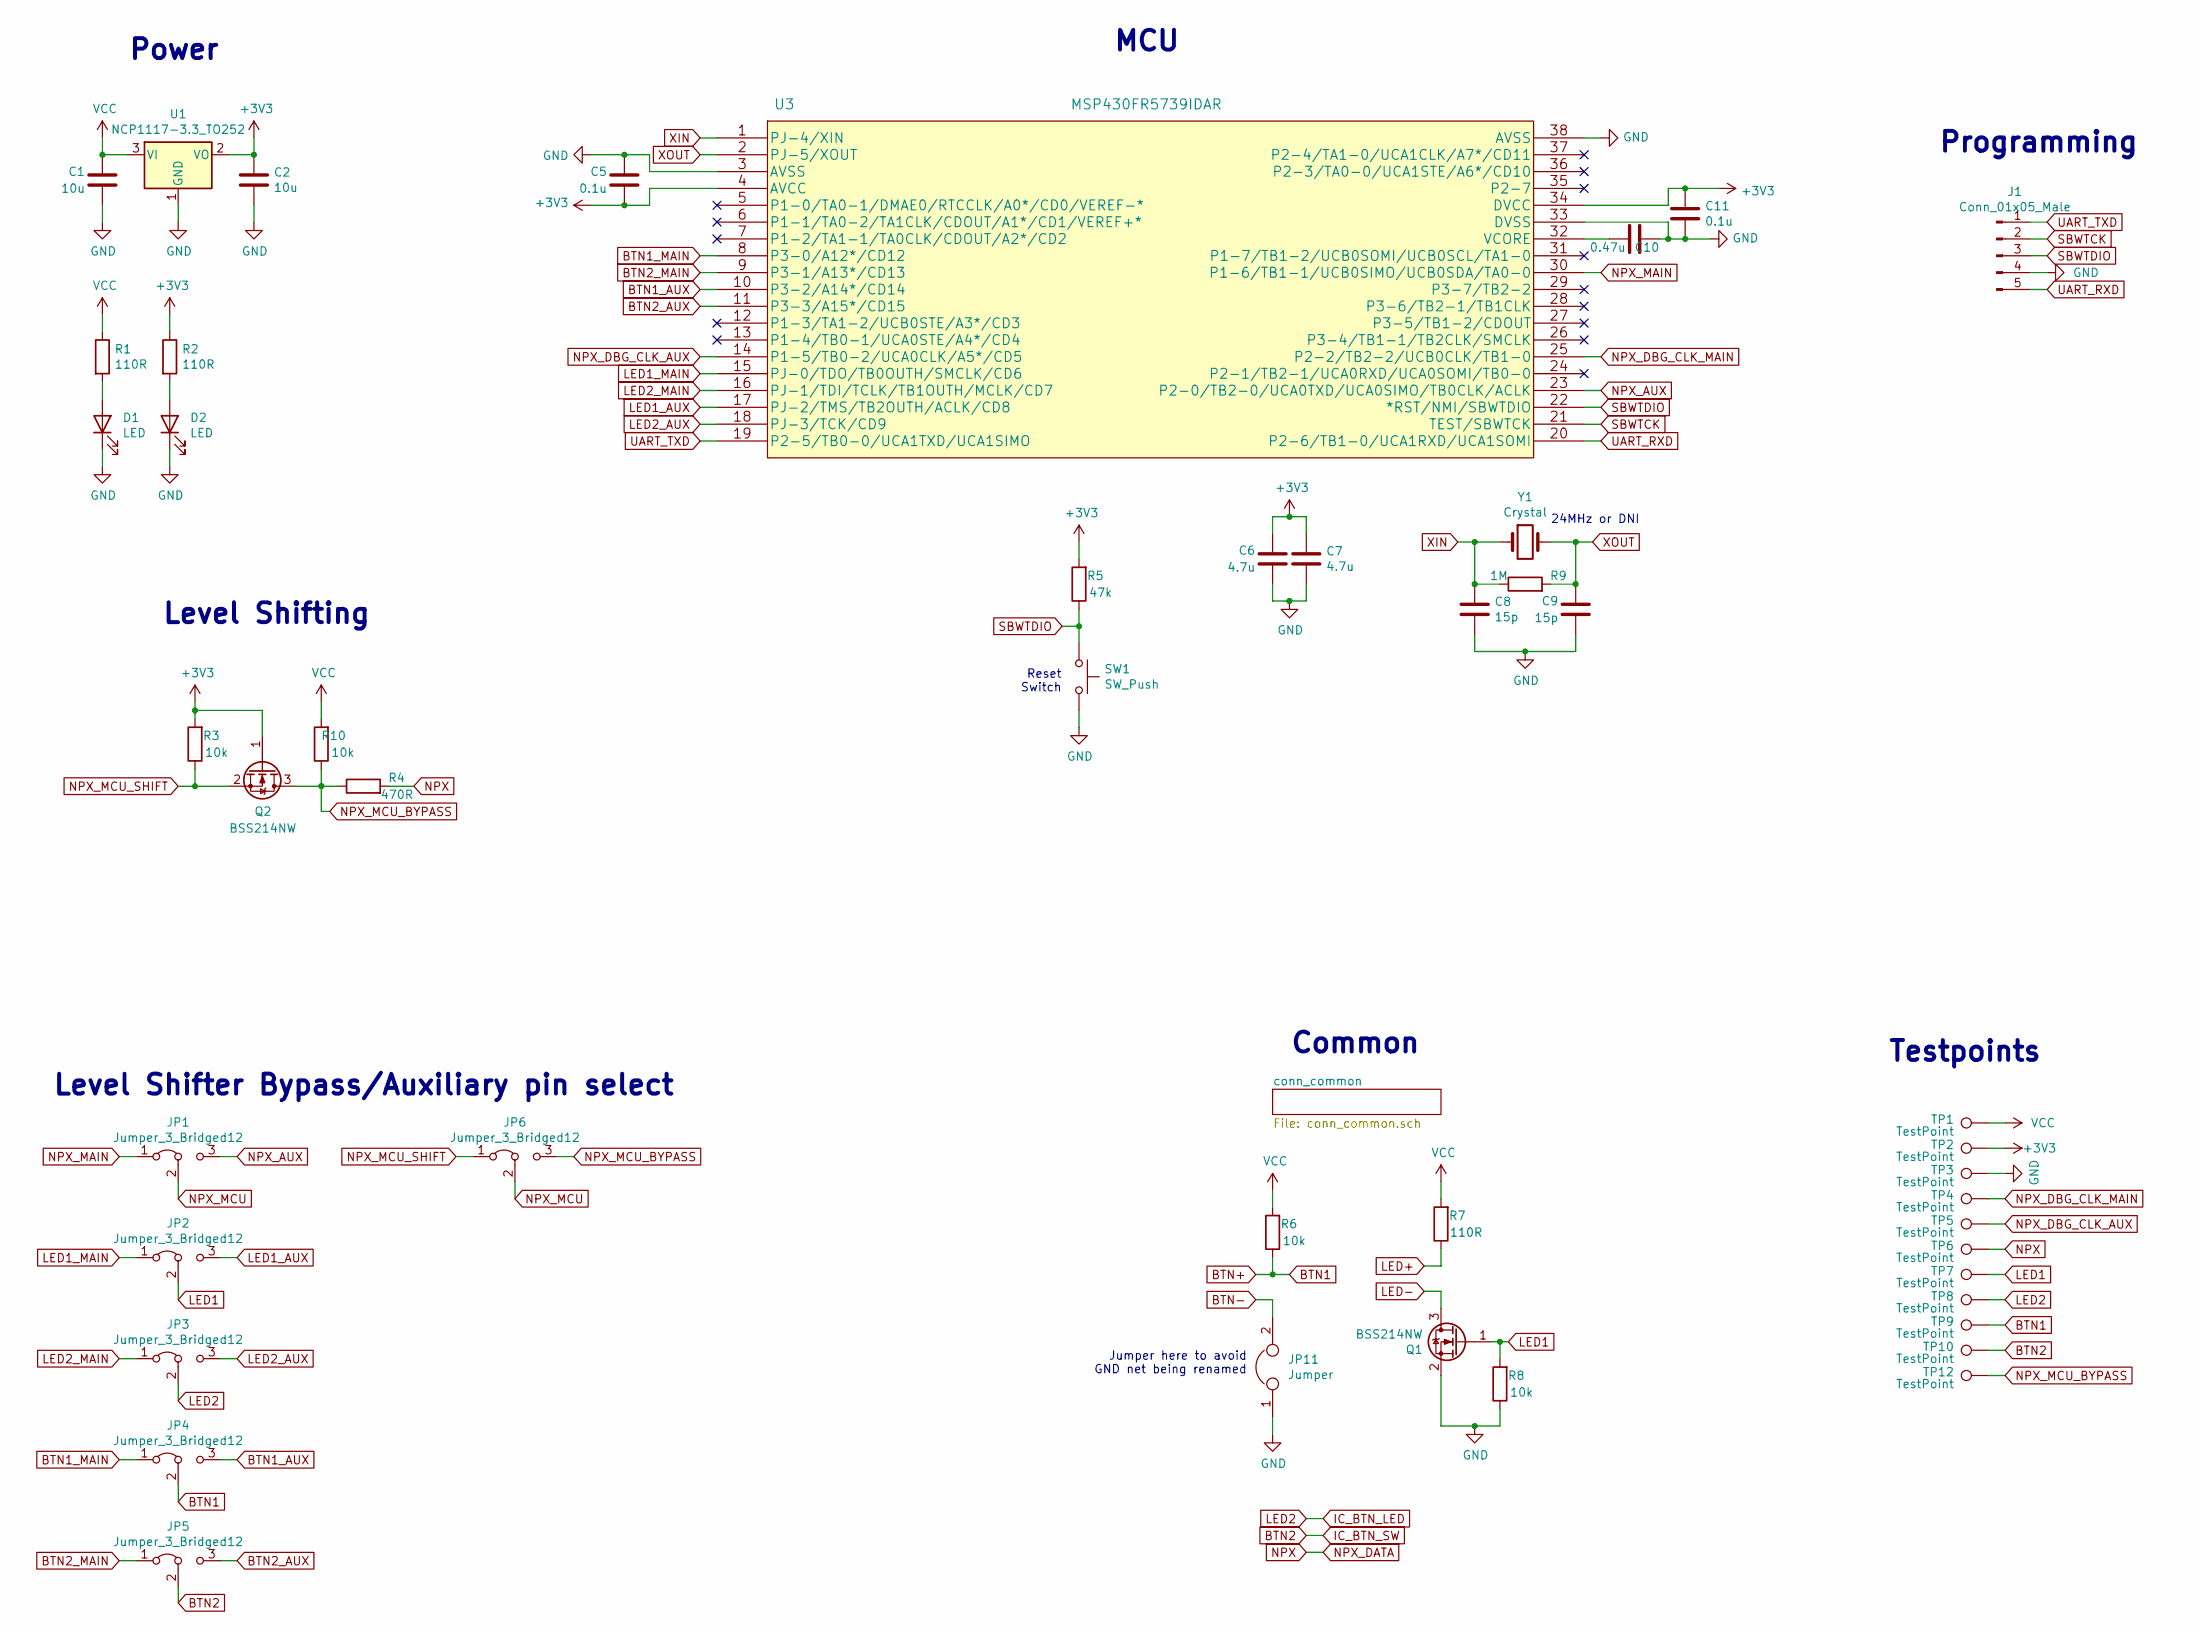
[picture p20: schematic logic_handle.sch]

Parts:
C1, C2: 10u; C_0805_2012Metric; Digikey 1276-6456-1-ND
C5, C11: 0.1u; C_0805_2012Metric; Digikey 478-10836-1-ND
C6, C7: 4.7u; C_0805_2012Metric; Digikey 1276-1259-1-ND
C8, C9: 15p; C_0805_2012Metric; Digikey 478-1306-1-ND
C10: 0.47u; C_0805_2012Metric; Digikey 478-10438-1-ND
D1, D2: LED; LED_0603_1608Metric; Digikey 160-1832-1-ND
J1: Conn_01x05_Male; PinHeader_1x05_P2.54mm_Vertical
JP1, JP2, JP3, JP4, JP5, JP6: Jumper_3_Bridged12; SolderJumper-3_P1.3mm_Bridged2Bar12_Pad1.0x1.5mm
JP11: Jumper; SolderJumper-2_P1.3mm_Bridged2Bar_Pad1.0x1.5mm
Q1, Q2: BSS214NW; SOT-323_SC-70; Digikey BSS214NWH6327XTSA1CT-ND
R1, R2, R7: 110R; R_0805_2012Metric; Digikey RMCF0805JT110RCT-ND
R3, R6, R8, R10: 10k; R_0805_2012Metric; Digikey RMCF0805JT10K0CT-ND
R4: 470R; R_0805_2012Metric; Digikey A129745CT-ND
R5: 47k; R_0805_2012Metric; Digikey A130144CT-ND
R9: 1M; R_0805_2012Metric; Digikey A106058CT-ND
SW1: SW_Push; SW_SPST_TL3342; Digikey EG5470CT-ND
TP1, TP2, TP3, TP4, TP5, TP6, TP7, TP8, TP9, TP10, TP12: TestPoint; TestPoint_Pad_2.0x2.0mm
U1: NCP1117-3.3_TO252; TO-252-2; Digikey NCP1117ST33T3GOSCT-ND
U3: MSP430FR5739IDAR; Digikey 296-29235-1-ND
Y1: Crystal; Crystal_SMD_AWSZT-CV-2Pin_3.7x3.1mm; Digikey 535-10028-2-ND

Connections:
+3V3: C2.1, C5.1, C6.2, C7.1, C11.1, Q2.1 (G), R2.1, R3.2, R5.2, TP2.1, U1.2 (VO), U3.4 (AVCC), U3.34 (DVCC)
BTN1_AUX: JP4.3 (B), U3.10 (P3-2/A14*/CD14)
BTN1_MAIN: JP4.1 (A), U3.8 (P3-0/A12*/CD12)
BTN2: JP5.2 (C), TP10.1; also elsewhere on the board
BTN2_AUX: JP5.3 (B), U3.11 (P3-3/A15*/CD15)
BTN2_MAIN: JP5.1 (A), U3.9 (P3-1/A13*/CD13)
BTN+: JP4.2 (C), R6.1, TP9.1; also elsewhere on the board
BTN-: JP11.2; also elsewhere on the board
GND: C1.1, C2.2, C5.2, C6.1, C7.2, C8.2, C9.1, C10.2, C11.2, D1.1 (K), D2.1 (K), J1.4, JP11.1, Q1.2 (S), R8.1, SW1.2, TP3.1, U1.1 (GND), U3.3 (AVSS), U3.33 (DVSS), U3.38 (AVSS); also elsewhere on the board
IC_BTN_LED: JP3.2 (C), TP8.1; also elsewhere on the board
LED1: JP2.2 (C), Q1.1 (G), R8.2, TP7.1
LED1_AUX: JP2.3 (B), U3.17 (PJ-2/TMS/TB2OUTH/ACLK/CD8)
LED1_MAIN: JP2.1 (A), U3.15 (PJ-0/TDO/TB0OUTH/SMCLK/CD6)
LED2_AUX: JP3.3 (B), U3.18 (PJ-3/TCK/CD9)
LED2_MAIN: JP3.1 (A), U3.16 (PJ-1/TDI/TCLK/TB1OUTH/MCLK/CD7)
LED+: R7.1; also elsewhere on the board
LED-: Q1.3 (D); also elsewhere on the board
NPX: R4.2, TP6.1; also elsewhere on the board
NPX_AUX: JP1.3 (B), U3.23 (P2-0/TB2-0/UCA0TXD/UCA0SIMO/TB0CLK/ACLK)
NPX_DBG_CLK_AUX: TP5.1, U3.14 (P1-5/TB0-2/UCA0CLK/A5*/CD5)
NPX_DBG_CLK_MAIN: TP4.1, U3.25 (P2-2/TB2-2/UCB0CLK/TB1-0)
NPX_MAIN: JP1.1 (A), U3.30 (P1-6/TB1-1/UCB0SIMO/UCB0SDA/TA0-0)
NPX_MCU: JP1.2 (C), JP6.2 (C)
NPX_MCU_BYPASS: JP6.3 (B), Q2.3 (D), R4.1, R10.1, TP12.1
NPX_MCU_SHIFT: JP6.1 (A), Q2.2 (S), R3.1
unnamed: C10.1, U3.32 (VCORE)
unnamed: D1.2 (A), R1.2
unnamed: D2.2 (A), R2.2
SBWTCK: J1.2, U3.21 (TEST/SBWTCK)
SBWTDIO: J1.3, R5.1, SW1.1, U3.22 (*RST/NMI/SBWTDIO)
UART_RXD: J1.5, U3.20 (P2-6/TB1-0/UCA1RXD/UCA1SOMI)
UART_TXD: J1.1, U3.19 (P2-5/TB0-0/UCA1TXD/UCA1SIMO)
VCC: C1.2, R1.1, R6.2, R7.2, R10.2, TP1.1, U1.3 (VI); also elsewhere on the board
XIN: C8.1, R9.1, U3.1 (PJ-4/XIN), Y1.1
XOUT: C9.2, R9.2, U3.2 (PJ-5/XOUT), Y1.2

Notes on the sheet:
Level Shifting
MCU
Power
Reset Switch
Level Shifter Bypass/Auxiliary pin select
Jumper here to avoid GND net being renamed
Programming
24MHz or DNI
Common
Testpoints


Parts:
H1, H2, H3, H4: MountingHole; MountingHole_2.7mm_M2.5
JBC1: Conn_01x04; JST_SH_SM04B-SRSS-TB_1x04-1MP_P1.00mm_Horizontal; Digikey SM04B-SRSS-TB
JHI1: Conn_01x04; JST_SH_SM04B-SRSS-TB_1x04-1MP_P1.00mm_Horizontal; Digikey SM04B-SRSS-TB
JNPX1: Conn_01x03; JST_PH_S3B-PH-SM4-TB_1x03-1MP_P2.00mm_Horizontal; Digikey 455-1750-1-ND
LOGO1: Logo_Open_Hardware_Small; OSHW-Logo_5.7x6mm_SilkScreen

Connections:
BTN2: JHI1.4; also elsewhere on the board
BTN+: JBC1.1; also elsewhere on the board
BTN-: JBC1.2; also elsewhere on the board
GND: JHI1.1, JNPX1.3; also elsewhere on the board
IC_BTN_LED: JHI1.3; also elsewhere on the board
LED+: JBC1.3; also elsewhere on the board
LED-: JBC1.4; also elsewhere on the board
NPX: JNPX1.1; also elsewhere on the board
VCC: JHI1.2, JNPX1.2; also elsewhere on the board

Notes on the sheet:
Neopixel Connector
Handle Interconnect
Button Connector
Vf = 2.8V
Mounting Holes

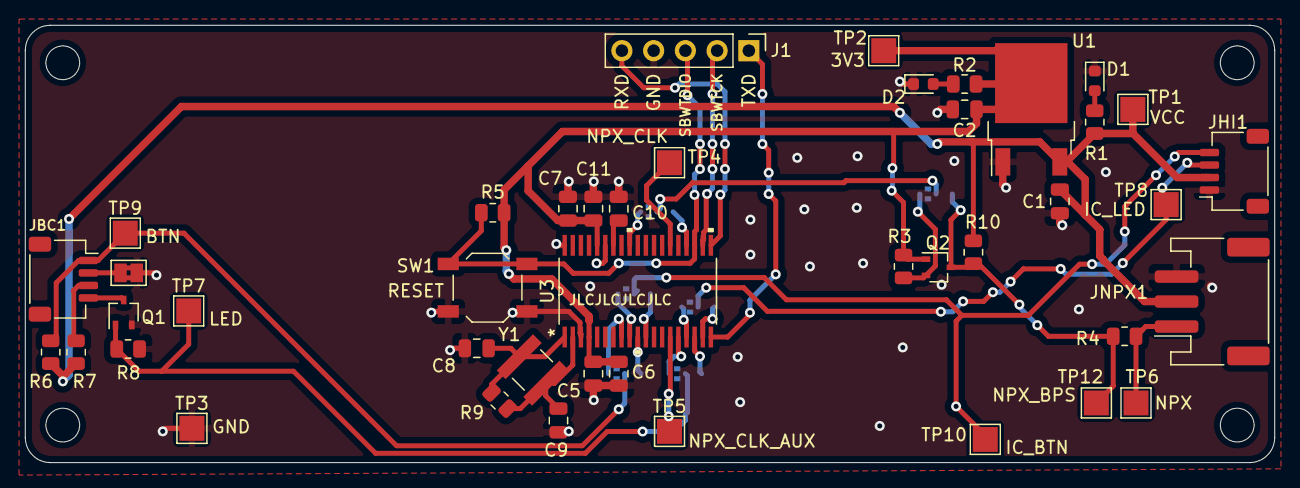
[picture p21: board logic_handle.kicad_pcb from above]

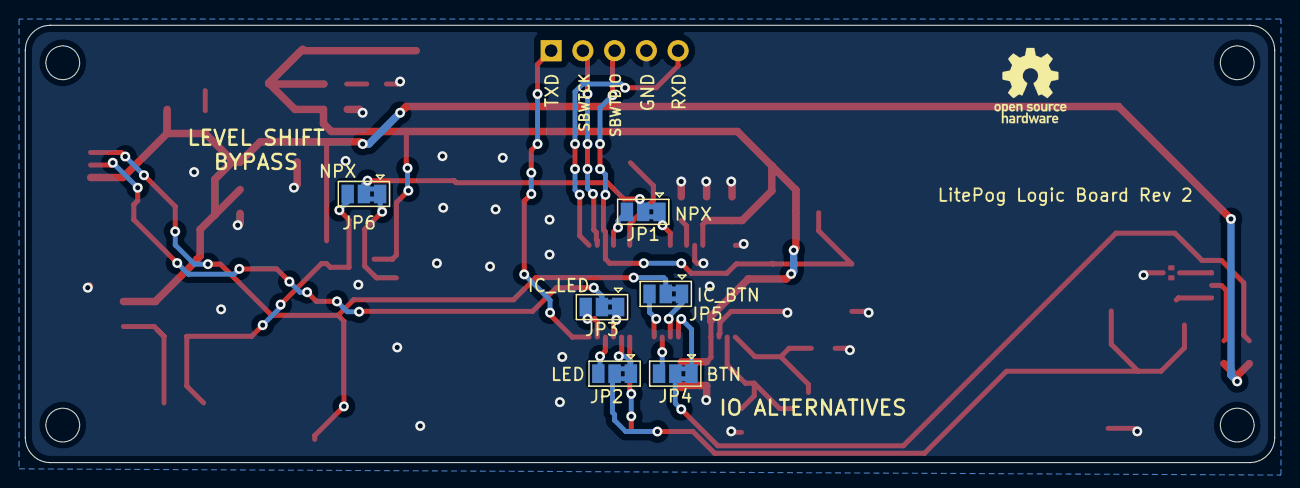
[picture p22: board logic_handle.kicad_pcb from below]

Board: 2 copper layers, 100.0 x 35.0 mm, 54 parts (7 on the bottom side), 35 nets.

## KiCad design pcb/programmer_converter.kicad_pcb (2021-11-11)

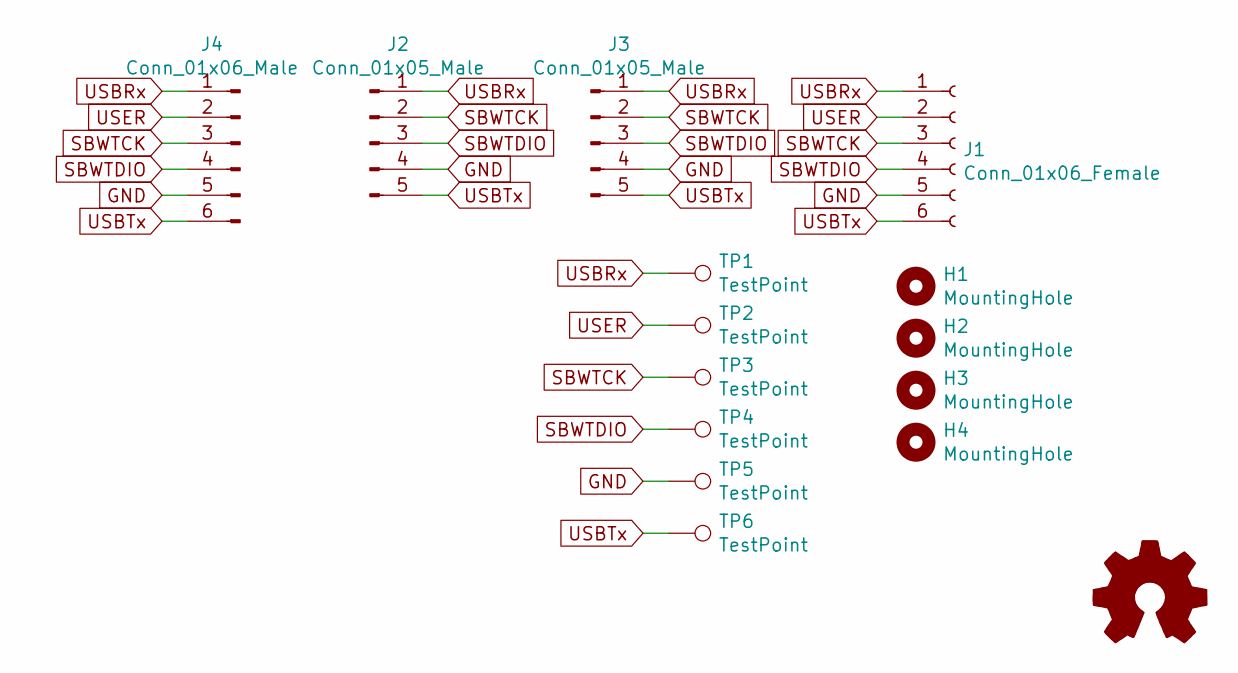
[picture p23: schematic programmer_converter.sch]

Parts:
H1, H2, H3, H4: MountingHole; MountingHole_2.7mm_M2.5
J1: Conn_01x06_Female; 851-87-006-20-001101
J2, J3: Conn_01x05_Male; PinHeader_1x05_P2.54mm_Vertical
J4: Conn_01x06_Male; PinHeader_1x06_P1.27mm_Horizontal
LOGO1: Logo_Open_Hardware_Small; OSHW-Logo_5.7x6mm_SilkScreen
TP1, TP2, TP3, TP4, TP5, TP6: TestPoint; TestPoint_Pad_2.0x2.0mm

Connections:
GND: J1.5, J2.4, J3.4, J4.5, TP5.1
SBWTCK: J1.3, J2.2, J3.2, J4.3, TP3.1
SBWTDIO: J1.4, J2.3, J3.3, J4.4, TP4.1
USBRx: J1.1, J2.1, J3.1, J4.1, TP1.1
USBTx: J1.6, J2.5, J3.5, J4.6, TP6.1
USER: J1.2, J4.2, TP2.1

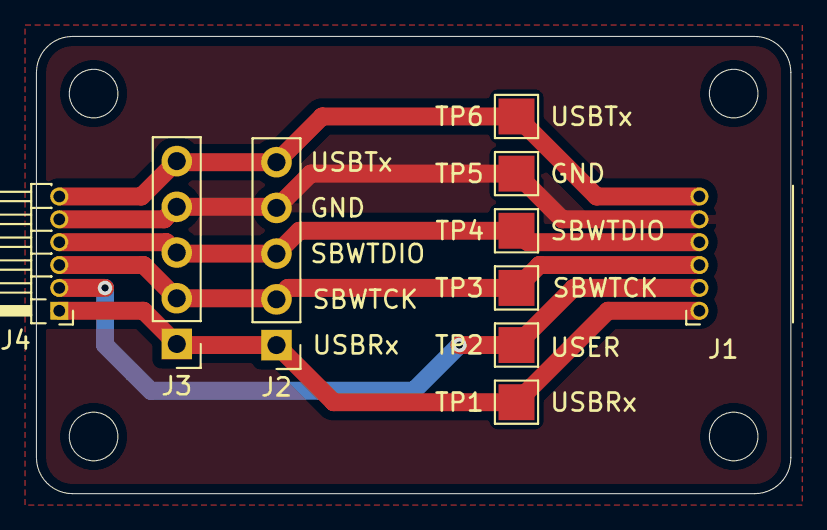
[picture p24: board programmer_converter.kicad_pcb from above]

Board: 2 copper layers, 41.9 x 25.4 mm, 15 parts (1 on the bottom side), 6 nets.

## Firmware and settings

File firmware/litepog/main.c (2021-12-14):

#include <msp430.h> 
#include <stdbool.h>
#include <stdint.h>
#include "init.h"
#include "ws2812.h"
#include "config.h"
#include "color.h"
#include "util.h"


typedef enum {
    GAME_PONG = 0,     // Rev 1 firmware game with improvements
    GAME_PINGPONG = 1, // Ping Pong game from promo video
    GAME_TUGOWAR = 2,  // Tug o' War game from promo video

    // Placeholder names for detecting when the end of the game list is reached
    _GAME_FIRST = GAME_PONG,
    _GAME_LAST = GAME_TUGOWAR,
} GameType;

volatile uint64_t counter;

// Store game type selection in FRAM
#pragma DATA_SECTION(game_type, ".infoB")
GameType game_type;

void drawCountDown(uint8_t state) {
    uint8_t i, j;
    uint8_t pos_left, pos_right;

    clearStrip();
    if(state < COUNTDOWN_NUMBER) {
        // Show countdown going up (red lights)
        for(i=0; i<=state; i++) {
            pos_left = NPX_MID_IDX - NPX_EVEN_LEDS - i*COUNTDOWN_LED_WIDTH;
            pos_right = NPX_MID_IDX - NPX_EVEN_LEDS + i*COUNTDOWN_LED_WIDTH;
            for(j=0; j<COUNTDOWN_LED_WIDTH; j++) {
                setLEDColor(pos_left + j, 255, 0, 0);
                setLEDColor(pos_right + j, 255, 0, 0);
            }
        }
    } else {
        // Show countdown finishing (green light)
        for(i=COUNTDOWN_MIN_IDX; i<=COUNTDOWN_MAX_IDX; i++)
            setLEDColor(i, 0, 255, 0);
    }
    showStrip();
}

void drawDemoPong(bool show) {
    static uint64_t last_frame = 0;
    static uint8_t pos = NPX_MID_IDX;
    static int8_t dir = 1;
    static uint8_t frame_div = DEMO_PONG_INTERVAL_DIV;
    if (counter > last_frame + DEMO_INTERVAL) {
        last_frame = counter;
        frame_div--;
        if(frame_div == 0) {
            frame_div = DEMO_PONG_INTERVAL_DIV;
            clearStrip();
            setLEDColor(DEMO_MIN_IDX, 0, 0, RETURN_ZONE_BRIGHTNESS);
            setLEDColor(DEMO_MAX_IDX, 0, 0, RETURN_ZONE_BRIGHTNESS);
            setLEDColor(pos, 0, 0, 255);
            pos += dir;
            if(pos <= DEMO_MIN_IDX)
                dir = 1;
            else if(pos >= DEMO_MAX_IDX)
                dir = -1;
            if(show)
                showStrip();
        }
    }
}

int8_t pingPongIdx(uint8_t pos) {
    if(NPX_EVEN_LEDS) {
        if(pos >= NPX_MID_IDX)
            return (int8_t)pos - NPX_MID_IDX;
        else
            return (int8_t)pos - NPX_MID_IDX + 1;
    } else {
        return (int8_t)pos - NPX_MID_IDX;
    }
}

void drawDemoPingPong(bool show) {
    static uint64_t last_frame = 0;
    static uint8_t pos = NPX_MID_IDX;
    int8_t side;
    static int8_t dir = 1;
    static uint8_t frame_div = DEMO_PINGPONG_INTERVAL_DIV;
    uint8_t i;
    if (counter > last_frame + DEMO_INTERVAL) {
        last_frame = counter;
        frame_div--;
        if(frame_div == 0) {
            frame_div = DEMO_PINGPONG_INTERVAL_DIV;
            clearStrip();
            for(i=DEMO_MIN_IDX; i<=DEMO_MAX_IDX; i++) {
                if(pingPongIdx(i))
                    setLEDColor(i, 0, 0, RETURN_ZONE_BRIGHTNESS);
            }
            pos += dir;
            side = pingPongIdx(pos);
            if(!(counter % DEMO_PINGPONG_RETURN_RATE)) {
                if(side > 0)
                    dir = -1;
                else if (side < 0)
                    dir = 1;
            }
            if(pos <= DEMO_MIN_IDX)
                dir = 1;
            else if(pos >= DEMO_MAX_IDX)
                dir = -1;

            setLEDColor(pos, 0, 0, 255);
            if(show)
                showStrip();
        }
    }
}

void drawDemoTugOWar(bool show) {
    static uint64_t last_frame = 0;
    static uint8_t pos = NPX_MID_IDX;
    static uint8_t frame_div = DEMO_TUGOWAR_INTERVAL_DIV;
    if (counter > last_frame + DEMO_INTERVAL) {
        last_frame = counter;
        frame_div--;
        if(frame_div == 0) {
            frame_div = DEMO_TUGOWAR_INTERVAL_DIV;
            pos += ((int32_t)fast_rand() % 3) - 1;
            clearStrip();
            setLEDColor(pos, 0, 0, 255);
            if(pos <= DEMO_MIN_IDX)
                pos += 1;
            else if(pos >= DEMO_MAX_IDX)
                pos -= 1;
            if(show)
                showStrip();
        }
    }
}

void drawGameSelectIndicator(void) {
    static uint64_t last_frame = 0;
    static HsvColor hsv = {0, 255, 100};
    RgbColor rgb;
    uint8_t i;
    if (counter > last_frame + DEMO_INTERVAL) {
        last_frame = counter;
        rgb = HsvToRgb(hsv);
        for(i=0; i<GAME_SELECT_WIDTH; i++)
            setLEDColor(
                    NPX_NUM_LEDS - 1 - i, rgb.r, rgb.g, rgb.b);

        showStrip();
        hsv.h++;
    }
}

void demoLoop(void) {
    bool countdown_started = false;
    void (*demo_anim)(bool);
    uint64_t countdown_start;
    uint8_t countdown_state = 0;

    switch(game_type) {
    case GAME_PONG:
        demo_anim = &drawDemoPong;
        break;
    case GAME_PINGPONG:
        demo_anim = &drawDemoPingPong;
        break;
    case GAME_TUGOWAR:
        demo_anim = &drawDemoTugOWar;
        break;
    }

    clearStrip();
    showStrip();

    while(1) {
        if(BTN_PxIN & BTN1_PIN)
            LED_PxOUT &= ~(LED1_PIN);
        else
            LED_PxOUT |= LED1_PIN;

        if(BTN_PxIN & BTN2_PIN)
            LED_PxOUT &= ~(LED2_PIN);
        else
            LED_PxOUT |= LED2_PIN;

        if(!(BTN_PxIN & (BTN1_PIN | BTN2_PIN))) {
            if(!countdown_started) {
                countdown_started = true;
                countdown_start = counter;
            }
            if(
                    counter >=
                    countdown_start + countdown_state*COUNTDOWN_INTERVAL) {
                drawCountDown(countdown_state++);

                if(countdown_state > COUNTDOWN_NUMBER) {
                    LED_PxOUT &= ~(LED1_PIN | LED2_PIN);
                    return;
                }
            }

        } else {
            // Reset countdown, show demo loop
            countdown_started = false;
            countdown_state = 0;
            (*demo_anim)(true);
        }
    }
}

// Returns 0 if Player 1  wins, 1 if Player 2 wins
uint8_t gameLoopPong(void) {
    int8_t dir;
    int32_t pos = NPX_NUM_LEDS / 2;
    uint64_t ball_counter = 0;
    int32_t ball_interval = PONG_BALL_INTERVAL_START;
    uint8_t i;
    ButtonState btn1, btn2;


    // Ball should move away from player that releases button first
    while(1) {
        if(BTN_PxIN & BTN1_PIN) {
            dir = 1;
            break;
        }

        if(BTN_PxIN & BTN2_PIN) {
            dir = -1;
            break;
        }
    }

    clearStrip();
    showStrip();

    while(1) {
        if(ball_counter + ball_interval <= counter) {
            ball_counter = counter;
            pos += dir;
            if(pos < 0)
                return 1;
            else if(pos >= NPX_NUM_LEDS)
                return 0;
            clearStrip();
            for(i=0; i<PONG_RETURN_ZONE_WIDTH; i++)
                setLEDColor(i, 0, 0, RETURN_ZONE_BRIGHTNESS);
            for(i=NPX_NUM_LEDS-1; i>=NPX_NUM_LEDS-PONG_RETURN_ZONE_WIDTH; i--)
                setLEDColor(i, 0, 0, RETURN_ZONE_BRIGHTNESS);
            setLEDColor(pos, 0, 0, 255);
            showStrip();
        }

        if(pos < PONG_RETURN_ZONE_WIDTH && dir < 0) {
            LED_PxOUT |= LED1_PIN;
            if(btnPressed(&btn1, BTN1_PIN)) {
                dir *= -1;
                ball_interval -= PONG_BALL_INTERVAL_SPEEDUP;
            }
        } else {
            LED_PxOUT &= ~(LED1_PIN);
            btn1 = BTN_WAIT;
        }

        if(pos >= NPX_NUM_LEDS - PONG_RETURN_ZONE_WIDTH && dir > 0) {
            LED_PxOUT |= LED2_PIN;
            if(btnPressed(&btn2, BTN2_PIN)) {
                dir *= -1;
                ball_interval -= PONG_BALL_INTERVAL_SPEEDUP;
            }
        } else {
            LED_PxOUT &= ~(LED2_PIN);
            btn2 = BTN_WAIT;
        }

        if(ball_interval < PONG_BALL_INTERVAL_MIN)
            ball_interval = PONG_BALL_INTERVAL_MIN;
    }
}

// Returns 0 if Player 1  wins, 1 if Player 2 wins
uint8_t gameLoopPingPong(void) {
    int8_t dir;
    int32_t pos = NPX_NUM_LEDS / 2;
    uint64_t ball_counter = 0;
    uint64_t cooldown = 0;
    int32_t ball_interval = PINGPONG_BALL_INTERVAL_START;
    uint8_t i;
    ButtonState btn1 = BTN_WAIT;
    ButtonState btn2 = BTN_WAIT;


    // Ball should move away from player that releases button first
    while(1) {
        if(BTN_PxIN & BTN1_PIN) {
            dir = 1;
            break;
        }

        if(BTN_PxIN & BTN2_PIN) {
            dir = -1;
            break;
        }
    }

    clearStrip();
    showStrip();

    while(1) {
        if(ball_counter + ball_interval <= counter) {
            ball_counter = counter;
            pos += dir;
            if(pos < 0)
                return 1;
            else if(pos >= NPX_NUM_LEDS)
                return 0;
            clearStrip();
            for(i=0; i<PINGPONG_RETURN_ZONE_WIDTH; i++)
                setLEDColor(i, 0, 0, RETURN_ZONE_BRIGHTNESS);
            for(i=NPX_NUM_LEDS-1; i>=NPX_NUM_LEDS-PINGPONG_RETURN_ZONE_WIDTH; i--)
                setLEDColor(i, 0, 0, RETURN_ZONE_BRIGHTNESS);
            setLEDColor(pos, 0, 0, 255);
            showStrip();
        }

        if(counter > cooldown) {
            cooldown = counter + PINGPONG_DEBOUNCE_TIME;
            if(btnPressed(&btn1, BTN1_PIN)) {
                btn1 = BTN_WAIT;
                if(pos < PINGPONG_RETURN_ZONE_WIDTH && dir < 0) {
                    dir *= -1;
                    ball_interval -= PINGPONG_BALL_INTERVAL_SPEEDUP;
                } else {
                    return 1;
                }
            }
            if(btnPressed(&btn2, BTN2_PIN)) {
                btn2 = BTN_WAIT;
                if(pos >= NPX_NUM_LEDS - PINGPONG_RETURN_ZONE_WIDTH && dir > 0) {
                    dir *= -1;
                    ball_interval -= PINGPONG_BALL_INTERVAL_SPEEDUP;
                } else {
                    return 0;
                }
            }
        }

        if(pos < PINGPONG_RETURN_ZONE_WIDTH && dir < 0) {
            LED_PxOUT |= LED1_PIN;
        } else {
            LED_PxOUT &= ~(LED1_PIN);
        }

        if(pos >= NPX_NUM_LEDS - PINGPONG_RETURN_ZONE_WIDTH && dir > 0) {
            LED_PxOUT |= LED2_PIN;
        } else {
            LED_PxOUT &= ~(LED2_PIN);
        }

        if(ball_interval < PINGPONG_BALL_INTERVAL_MIN)
            ball_interval = PINGPONG_BALL_INTERVAL_MIN;
    }
}

// Returns 0 if Player 1  wins, 1 if Player 2 wins
uint8_t gameLoopTugOWar(void) {
    int32_t pos = NPX_NUM_LEDS / 2;
    uint64_t cooldown = 0;
    ButtonState btn1 = BTN_WAIT;
    ButtonState btn2 = BTN_WAIT;

    clearStrip();
    showStrip();

    while(1) {
        if(pos < 0)
            return 1;
        else if(pos >= NPX_NUM_LEDS)
            return 0;
        clearStrip();
        setLEDColor(pos, 0, 0, 255);
        showStrip();
        if(counter > cooldown) {
            cooldown = counter + TUGOWAR_DEBOUNCE_TIME;
            if(btnPressed(&btn1, BTN1_PIN)) {
                btn1 = BTN_WAIT;
                pos++;
            }
            if(btnPressed(&btn2, BTN2_PIN)) {
                btn2 = BTN_WAIT;
                pos--;
            }
        }
    }
}

void winnerLoop(uint8_t winner) {
    uint8_t i = 0;
    uint8_t j;
    uint8_t winner_idx, loser_idx, idx1, idx2;
    uint64_t anim_start = counter;

    LED_PxOUT &= 0;
    clearStrip();
    showStrip();
    while(i<WINNER_NUMBER*2) {
        if (counter >= anim_start + i*WINNER_INTERVAL) {
            if(i%2) {
                clearStrip();
            } else {
                for(j=0; j < WINNER_LED_WIDTH; j++) {
                    idx1 = j;
                    idx2 = NPX_NUM_LEDS - 1 - j;
                    if(winner) {
                        loser_idx = idx1;
                        winner_idx = idx2;
                    } else {
                        loser_idx = idx2;
                        winner_idx = idx1;
                    }
                    setLEDColor(winner_idx, 0, 255, 0);
                    setLEDColor(loser_idx, 255, 0, 0);
                }
            }
            showStrip();
            i++;
        }
    }
}

void nextGame(void) {
    if(game_type == _GAME_LAST)
        game_type =_GAME_FIRST;
    else
        game_type++;
}

void prevGame(void) {
    if(game_type == _GAME_FIRST)
        game_type =_GAME_LAST;
    else
        game_type--;
}


void gameSelectLoop(void) {
    ButtonState btn1 = BTN_WAIT;
    ButtonState btn2 = BTN_WAIT;
    uint64_t cooldown = 0;
    while(1) {
        if(counter > cooldown) {
            cooldown = counter + GAME_SELECT_DEBOUNCE_TIME;
            if(btnPressed(&btn1, BTN1_PIN)) {
                btn1 = BTN_WAIT;
                nextGame();
                continue;
            }
            if(btnPressed(&btn2, BTN2_PIN)) {
                btn2 = BTN_WAIT;
                prevGame();
                continue;
            }
        }
        switch(game_type) {
        case GAME_PONG:
            drawDemoPong(false);
            break;
        case GAME_PINGPONG:
            drawDemoPingPong(false);
            break;
        case GAME_TUGOWAR:
            drawDemoTugOWar(false);
            break;
        }
        drawGameSelectIndicator();
    }
}


int main(void)
{
    uint8_t winner;
	WDTCTL = WDTPW | WDTHOLD;	// stop watchdog timer
	
	fast_srand(PRNG_SEED);

	initGpio();

	initClock();

	initStrip();

	initTimer();

	__enable_interrupt();

	if(!(BTN_PxIN & BTN2_PIN)) {
	    // Activate game selection if button 2 (power handle side)
	    // is held down when turning on
	    gameSelectLoop();
	} else {
        while(1) {
            demoLoop();
            switch(game_type) {
            case GAME_PONG:
                winner = gameLoopPong();
                break;
            case GAME_PINGPONG:
                winner = gameLoopPingPong();
                break;
            case GAME_TUGOWAR:
                winner = gameLoopTugOWar();
                break;
            }
            winnerLoop(winner);
        }
	}

	return 0;
}

// TB1 Interrupt Vector handler
#pragma vector=TIMER1_B1_VECTOR
__interrupt void TIMER1_B1_ISR(void) {
  switch(__even_in_range(TB1IV,14))
  {
    case  0: break;                          // No interrupt
    case  2: break;
    case  4: break;
    case  6: break;                          // reserved
    case  8: break;                          // reserved
    case 10: break;                          // reserved
    case 12: break;                          // reserved
    case 14:
        //overflow
        counter++;
        break;
    default: break;
  }
}

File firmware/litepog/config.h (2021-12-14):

/*
 * config.h
 *
 *  Created on: Nov 16, 2021
 *      Author: Jasper
 */

#ifndef CONFIG_H_
#define CONFIG_H_

// Number of LEDs in Neopixel strip
#define NPX_NUM_LEDS 30

// Index of middle LED
#define NPX_MID_IDX (NPX_NUM_LEDS/2)

// True if even number of LEDs
#define NPX_EVEN_LEDS (!(NPX_NUM_LEDS % 2))

// Seed for pseudo-random number generator
#define PRNG_SEED 0xB00B

// Time to wait between allowing button edges during game select
#define GAME_SELECT_DEBOUNCE_TIME 20

// Width of game selection menu indicator
#define GAME_SELECT_WIDTH 6

// Time between demo animation frames
#define DEMO_INTERVAL 10

// Frame divisor for pong demo animation
#define DEMO_PONG_INTERVAL_DIV 4

// Frame divisor for ping pong demo animation
#define DEMO_PINGPONG_INTERVAL_DIV 4

// Frame divisor for tug o' war demo animation
#define DEMO_TUGOWAR_INTERVAL_DIV 2

// Chance of ball being returned each frame of ping pong demo animation (1/N)
#define DEMO_PINGPONG_RETURN_RATE 9

// Width of the demo animation
#define DEMO_WIDTH 8

#define DEMO_MIN_IDX (NPX_MID_IDX - DEMO_WIDTH/2)
#define DEMO_MAX_IDX (NPX_MID_IDX + DEMO_WIDTH/2 - ((DEMO_WIDTH + 1) % 2))

// Time between countdown ticks
#define COUNTDOWN_INTERVAL 700

// Number of LEDs lit up for each countdown tick
#define COUNTDOWN_LED_WIDTH (1 + NPX_EVEN_LEDS)

// Number of countdown ticks before game start
#define COUNTDOWN_NUMBER 3

#define COUNTDOWN_MIN_IDX (NPX_MID_IDX - ((COUNTDOWN_NUMBER - 1)*COUNTDOWN_LED_WIDTH + NPX_EVEN_LEDS))
#define COUNTDOWN_MAX_IDX (NPX_MID_IDX + (COUNTDOWN_NUMBER - 1)*COUNTDOWN_LED_WIDTH)

// Brightness of ball return zones
#define RETURN_ZONE_BRIGHTNESS 15

// Initial time between ball events for pong
#define PONG_BALL_INTERVAL_START 70

// Amount of speedup after each rally for pong
#define PONG_BALL_INTERVAL_SPEEDUP 5

// Minimum interval time (max ball speed) for pong
#define PONG_BALL_INTERVAL_MIN 40

// Size of return zone for pong
#define PONG_RETURN_ZONE_WIDTH 3

// Initial time between ball events for pong
#define PINGPONG_BALL_INTERVAL_START 70

// Amount of speedup after each rally for pong
#define PINGPONG_BALL_INTERVAL_SPEEDUP 5

// Minimum interval time (max ball speed) for pong
#define PINGPONG_BALL_INTERVAL_MIN 10

// Size of return zone for pong
#define PINGPONG_RETURN_ZONE_WIDTH (NPX_MID_IDX - NPX_EVEN_LEDS)

// Debounce time for ping pong button reads
#define PINGPONG_DEBOUNCE_TIME 3

// Debounce time for tug o' war button reads
#define TUGOWAR_DEBOUNCE_TIME 3

// Time between winner animation frames
#define WINNER_INTERVAL 300

// Number of LEDs to flash per side
#define WINNER_LED_WIDTH 3

// Number of times the winner animation flashes
#define WINNER_NUMBER 5


// Hardware specific config
#if defined(LITEPOG_EXP430)  // MSP-EXP430FR5739

// Neopixel is driven by UCB0
#define NPX_UCxCTLW0 UCB0CTLW0
#define NPX_UCxBR0   UCB0BR0
#define NPX_UCxTXBUF UCB0TXBUF
#define NPX_UCxSTATW UCB0STATW
#define NPX_UCxIFG   UCB0IFG

// Neopixel data pin is P1.6 (UCB0SIMO)
#define NPX_PxDIR  P1DIR
#define NPX_PxSEL0 P1SEL0
#define NPX_PxSEL1 P1SEL1
#define NPX_PIN    BIT6

// UCB0 SPI clock pin is P2.2 (used for timing debug)
#define NPX_DBG_CLK_PxDIR  P2DIR
#define NPX_DBG_CLK_PxSEL0 P2SEL0
#define NPX_DBG_CLK_PxSEL1 P2SEL1
#define NPX_DBG_CLK_PIN    BIT2

// Buttons are connected to P4
#define BTN_PxDIR P4DIR
#define BTN_PxIN  P4IN
// Button 1 (connected to logic handle) is on P4.0
#define BTN1_PIN BIT0
// Button 2 (connected to power handle) is on P4.1
#define BTN2_PIN BIT1

// EXP430 board requires internal pullups
#define BTN_PULLUP_EN
#define BTN_PxREN P4REN
#define BTN_PxOUT P4OUT

// LEDs are connected to PJ
#define LED_PxDIR PJDIR
#define LED_PxOUT PJOUT
// LED 1 (connected to logic handle) is on PJ.0
#define LED1_PIN BIT0
// LED 2 (connected to power handle) is on PJ.1
#define LED2_PIN BIT1

#elif defined(LITEPOG_MAIN)  // LitePog mainboard (default config)

// Neopixel is driven by UCB0
#define NPX_UCxCTLW0 UCB0CTLW0
#define NPX_UCxBR0   UCB0BR0
#define NPX_UCxTXBUF UCB0TXBUF
#define NPX_UCxSTATW UCB0STATW
#define NPX_UCxIFG   UCB0IFG

// Neopixel data pin is P1.6 (UCB0SIMO)
#define NPX_PxDIR  P1DIR
#define NPX_PxSEL0 P1SEL0
#define NPX_PxSEL1 P1SEL1
#define NPX_PIN    BIT6

// UCB0 SPI clock pin is P2.2 (used for timing debug)
#define NPX_DBG_CLK_PxDIR  P2DIR
#define NPX_DBG_CLK_PxSEL0 P2SEL0
#define NPX_DBG_CLK_PxSEL1 P2SEL1
#define NPX_DBG_CLK_PIN    BIT2

// Buttons are connected to P3
#define BTN_PxDIR P3DIR
#define BTN_PxIN  P3IN
// Button 1 (connected to logic handle) is on P3.0
#define BTN1_PIN BIT0
// Button 2 (connected to power handle) is on P3.1
#define BTN2_PIN BIT1

// LEDs are connected to PJ
#define LED_PxDIR PJDIR
#define LED_PxOUT PJOUT
// LED 1 (connected to logic handle) is on PJ.0
#define LED1_PIN BIT0
// LED 2 (connected to power handle) is on PJ.1
#define LED2_PIN BIT1

#elif defined(LITEPOG_ALT)  // LitePog mainboard (alt config)
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

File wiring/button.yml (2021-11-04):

connectors:
  S1:
    type: '<a href="https://www.digikey.ca/en/products/detail/e-switch/PV7F2Y0SS-341/2116217">SWITCH PUSHBUTTON SPDT 2A 48V</a>'
    subtype: pin
    pinlabels: ['1', '2', '3', '4', (+), (-)]
    supplier: DigiKey
    spn: 141-PV7F2Y0SS-341-ND
    manufacturer: E-Switch
    mpn: PV7F2Y0SS-341
    image:
      src: res/pv7.svg

  C1:
    type: '<a href="https://www.adafruit.com/product/4210">JST SH</a>'
    subtype: plug
    pinlabels: [BTN+, BTN-, LED+, LED-]
    supplier: Adafruit
    spn: 4210
    ignore_in_bom: true  # Handle wire and connector as additional part
    image:
      src: res/sh-4.svg
      height: 100
    additional_components:
      -
        type: JST SH 4-pin Cable - 100mm Long
        subtype: https://www.adafruit.com/product/4210
        qty: 0.5
        supplier: Adafruit
        spn: 4210

cables:
  W1:
    gauge: 28 AWG
    length: 2 cm
    wirelabels: [BTN+, BTN-, LED+, LED-]
    colors: [BK, RD, BU, YE]
    ignore_in_bom: true  # JST connector and wire is a single part

connections:
  -
    - S1: ['3', '4', (+), (-)]
    - W1: [BTN+, BTN-, LED+, LED-]
    - C1: [BTN+, BTN-, LED+, LED-]

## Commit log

2021-11-03 wiring: Add wiring diagrams
2021-11-04 wiring: conform to JST pin numbering standard, add drawing for PH connectors
2021-11-04 pcb: Finish power handle schematic, start layout
    [conn_common.sch, logic_handle.kicad_pcb, logic_handle.sch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]
2021-11-04 pcb: remove leftover BOM file
2021-11-05 pcb: redo power handle layout
    [power_handle.kicad_pcb]
2021-11-05 pcb: finish routing of power handle
    [power_handle.kicad_pcb]
2021-11-05 pcb: cleanup power handle silkscreen, edge cuts
    [conn_common.sch, power_handle.FCStd, power_handle.kicad_pcb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]
2021-11-05 pcb: Create programming adapter
    [programmer_converter.FCStd, programmer_converter.kicad_pcb, programmer_converter.sch]
2021-11-06 pcb: Add testpoint labels to power handle
    [power_handle.kicad_pcb]
2021-11-10 [WIP]: Initial proof of concept for neopixel driver
2021-11-10 WIP: fix SIMO held high after transmit
    [ws2812.c]
2021-11-10 [WIP]: fix SIMO prematurely goes high
    [ws2812.c]
2021-11-11 Create Logic PCB (#2)
    [logic_handle.kicad_pcb, logic_handle.sch]
2021-11-11 power_handle: Add second ground layer, more info on silkscreen (#3)
    [power_handle.kicad_pcb]
2021-11-11 pcb: set gerber export locations (#4)
    - logic_handle: update fill zones
    [logic_handle.kicad_pcb, programmer_converter.kicad_pcb]
2021-11-11 programmer_converter: Add serial number locator for JLCPCB (#5)
    [programmer_converter.kicad_pcb]
2021-11-11 pcb: Update mech CAD files for PCBs (#6)
    [logic_handle.FCStd, power_handle.FCStd, programmer_converter.FCStd]
2021-11-11 pcb: Cleanup BOM items (#7)
    Replaced out of stock components with substitutes
    [logic_handle.sch, power_handle.sch, programmer_converter.sch]
2021-11-16 pcb: set default print directory to local dir
2021-11-28 pcb: bringup notes (#12)
2021-12-01 firmware: rainbow demo animation (fixes #17)
    [config.h, main.c]
2021-12-01 firmware: fix bug with countdown hanging when buttons start off pressed (fixes #16)
    [main.c]
2021-12-13 pcb: add power handle testing notes (#21)
2021-12-13 pcb: add full assembly notes (#22)
2021-12-13 pcb: implement improvements described in rev 1 bringup notes (#23)
    [logic_handle.kicad_pcb, logic_handle.sch, power_handle.kicad_pcb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]
2021-12-13 pcb: add pre-bringup notes for rev2 (#24)
2021-12-13 Revert "pcb: add pre-bringup notes for rev2 (#24)" (#25)
    This reverts commit d58d3a59f6f3c0d3dee3896672142f88f7fb4037.
2021-12-13 Revert "pcb: implement improvements described in rev 1 bringup notes (#23)" (#26)
    This reverts commit 01e55846632a9cef383a24172751afed95ee1909.
    [logic_handle.kicad_pcb, logic_handle.sch, power_handle.kicad_pcb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]
2021-12-13 mech: import rev1 SolidWorks files from GrabCAD (#27)
    [18650_prot.SLDPRT, 90592A080_Steel Hex Nut.SLDPRT, 91290A106_Black-Oxide Alloy Steel Socket Head Screw.SLDPRT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]
2021-12-13 mech: add rev 1 assembly notes
2021-12-13 wiring: add system wiring diagram
2021-12-13 wiring: update readme to indicate system diagram file type (#30)
2021-12-14 pcb: implement improvements described in rev 1 bringup notes (#35)
    [logic_handle.kicad_pcb, logic_handle.sch, power_handle.kicad_pcb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]
2021-12-14 pcb: add pre-bringup notes for rev2 (#36)
2021-12-14 firmware: implement improvements from playtest notes (#37)
    - Add game type selction (hold down BTN2 on POR)
    - hold down BTN2 on POR to trigger
    - BTN1 and BTN2 to scroll through game types
    - Game type saved to FRAM (remembered on next POR)
    - Unique demo animations per game type
    - Pong (original game)
    - Return zone width is now configurable
    - Return zone is dimly lit
    - PingPong (new game)
    - Based on Light Pong Ping Pong game mode
    - Tug O' War (new game)
    - Based on Light Pong Tug O' War game mode
    - Fix countdown not being centered properly
    [config.h, main.c]
2021-12-24 mech: update mechanical CAD to rev2 (#39)
    [18650_prot.SLDPRT, 90592A080_Steel Hex Nut.SLDPRT, 91290A106_Black-Oxide Alloy Steel Socket Head Screw.SLDPRT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]
